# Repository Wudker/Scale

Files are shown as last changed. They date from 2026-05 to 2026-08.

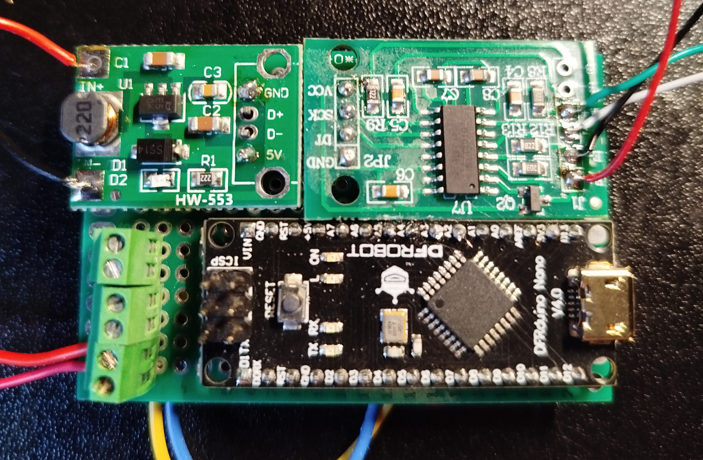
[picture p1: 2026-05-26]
Hardware/Photos/img_01.jpg

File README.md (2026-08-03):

# Load Cell Digital Scale

Load Cell Digital Scale is a compact standalone weighing device built around a strain-gauge load cell, HX711 converter and SSD1306 OLED display. The microcontroller converts the measured signal using an experimentally determined calibration factor and applies exponential filtering to reduce short-term fluctuations. Measurements are displayed in grams or kilograms, while automatic startup tare and a physical button provide zero adjustment. The electronics and weighing platform are integrated into a compact 3D-printed enclosure.

## Technologies

`Arduino` `C/C++` `Load cell` `HX711` `SSD1306 OLED` `Adafruit GFX` `I2C` `Exponential filtering` `3D printing`

## Usage and development status

Place the scale on a stable surface and power it on without any load to allow automatic taring. Use the physical button whenever manual re-taring is required, then place the object on the platform and read its mass from the display. The prototype has been built and tested, but broader validation is still required to evaluate repeatability, drift, nonlinearity and temperature effects. Future improvements may include overload detection and additional measurement compensation.

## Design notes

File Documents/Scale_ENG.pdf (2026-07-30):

# Scale Project

Final Project Documentation

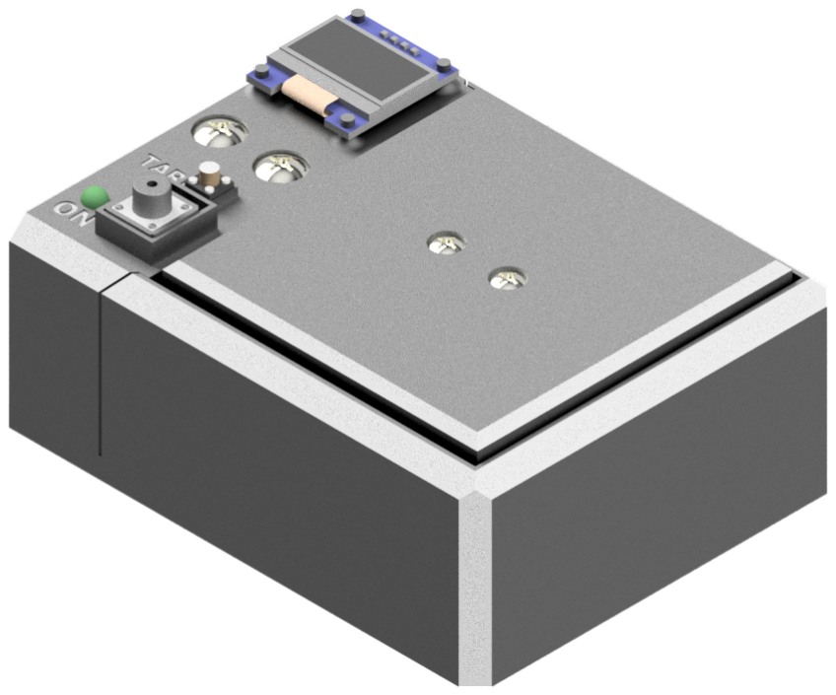
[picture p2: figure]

Author | Bartłomiej Dusza, Eng.
Date | July 20, 2026
Version | 1.0

This document summarizes the project and describes the assumptions, design and operation of the device.

# Contents

1 Introduction | 2
2 Electronics | 3
3 Mechanical Design | 5
4 Software | 7
5 Validation | 12

# 1 Introduction

## 1.1 Objective

The objective of the project was to design and build a simple scale for everyday use.

## 1.2 Operating Principle

The measurement principle is based on the linear relationship between stress and strain in the material from which the load cell is made. According to Hooke’s law, the deformation of the beam is proportional to the applied force. Strain gauges attached to the beam respond to deformation by changing their resistance. Connected in a Wheatstone bridge, they convert this change into a voltage signal.

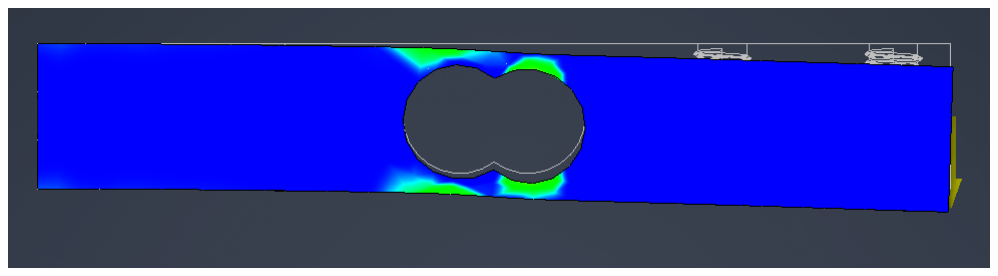
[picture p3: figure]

Figure 1.1: Visualization of load-cell deflection.

Because of the expected loads and material properties, load-cell deflection is very small and reaches only several tens of micrometres. The Wheatstone bridge output therefore requires amplification and conversion before it can be read by the microcontroller.

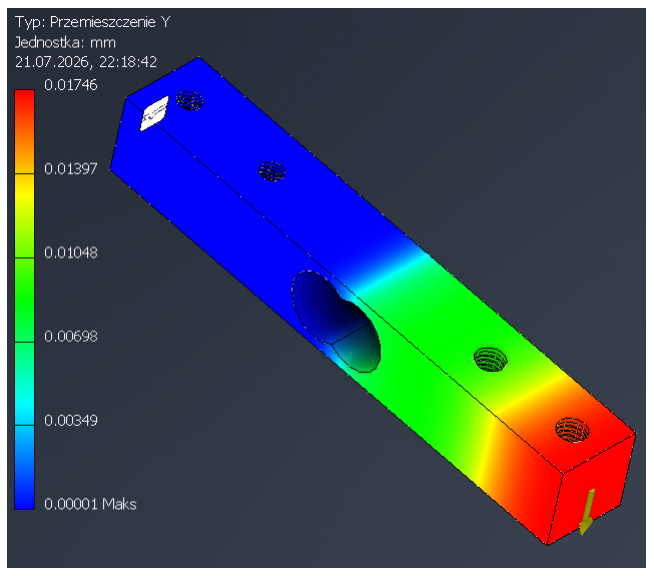
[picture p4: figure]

Figure 1.2: Example load-cell displacement.

# 2 Electronics

## 2.1 Selected Modules

After analyzing the project requirements, ready-made electronic modules were selected.

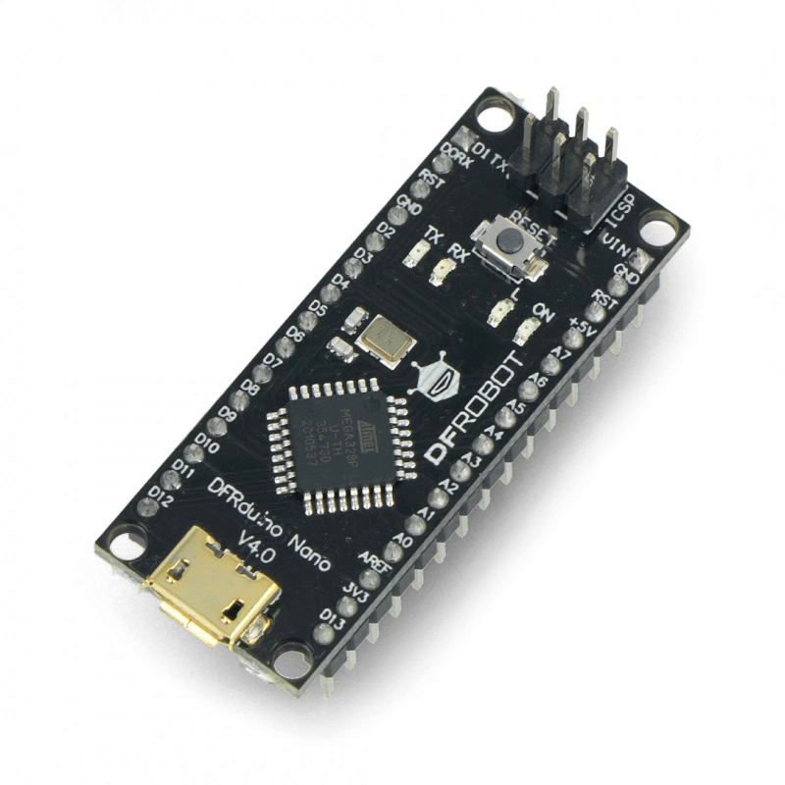
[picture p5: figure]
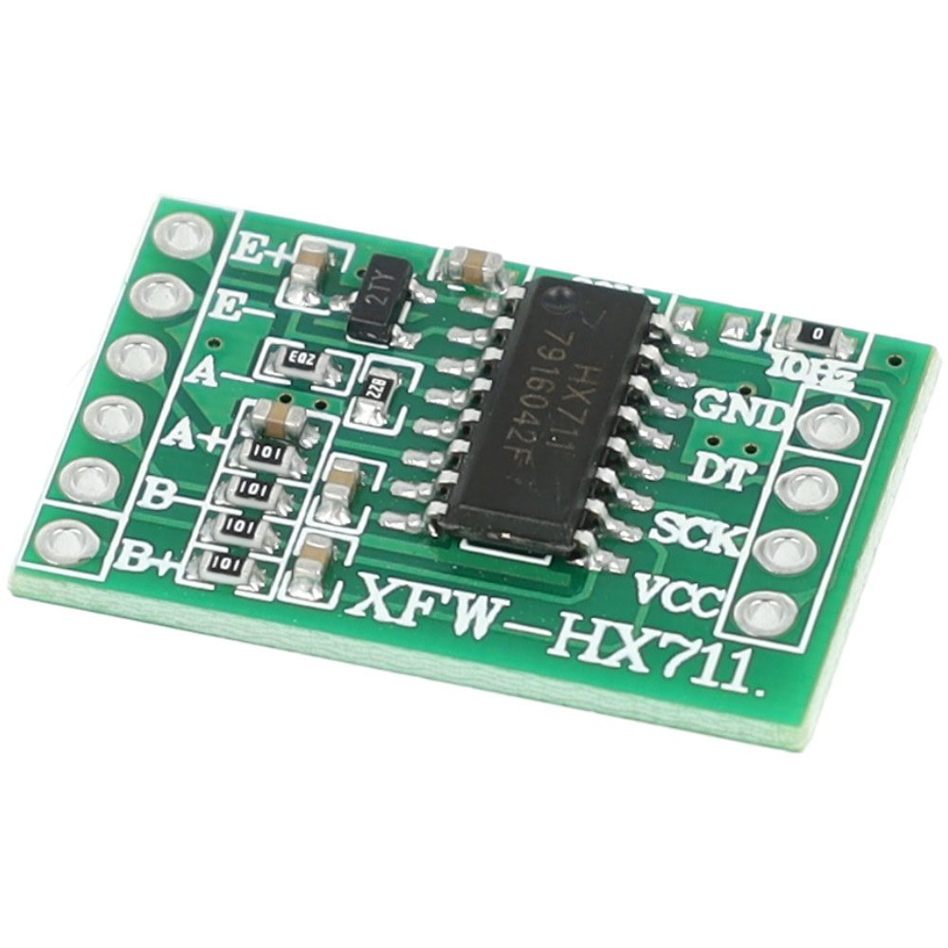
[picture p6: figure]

(a) Microcontroller. | (b) Load-cell amplifier.

The ATtiny85 microcontroller was selected initially. However, because the display had to be supported, it was replaced with the more capable DFRduino Nano development board [1], equipped with an ATmega328 microcontroller. Its availability, sufficient capabilities and favorable purchase price of PLN 20 were the main reasons for this choice.

The HX711 [2], a 24-bit analog-to-digital converter with an integrated programmable gain amplifier, was used to process the Wheatstone bridge signal.

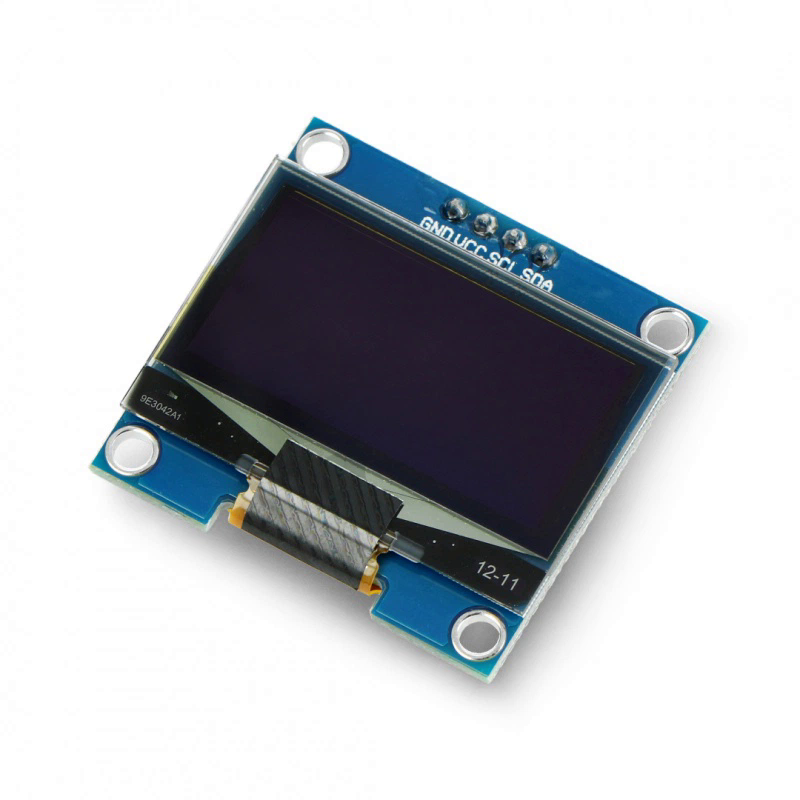
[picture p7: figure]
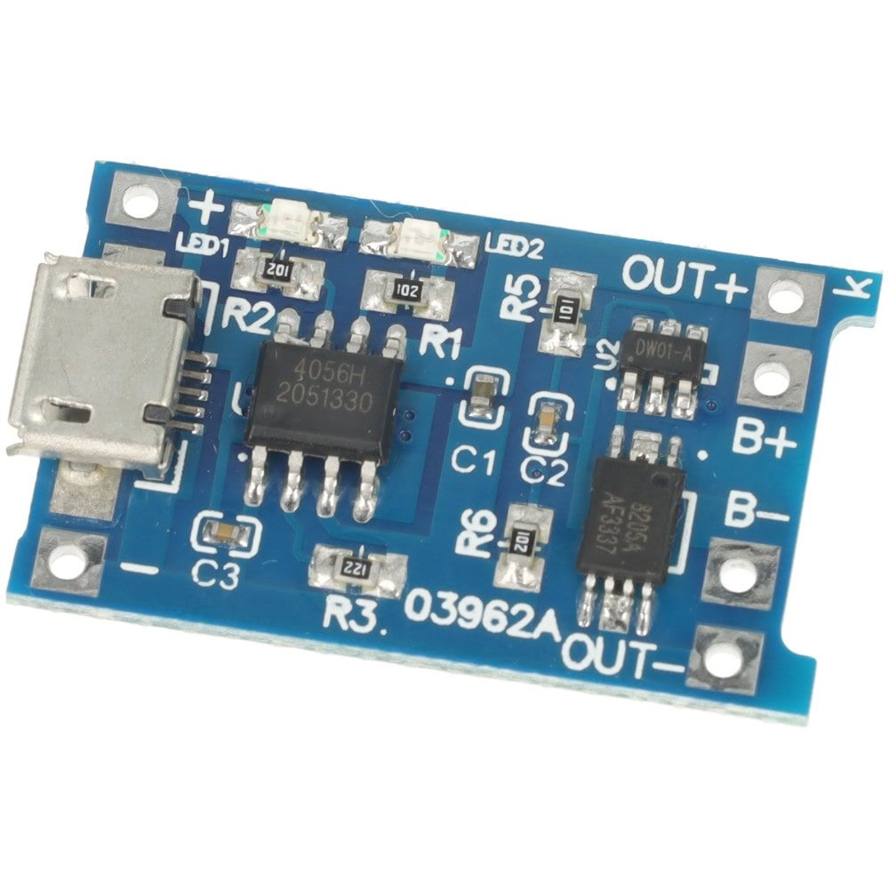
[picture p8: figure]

(a) Cell charging and protection module. | (b) OLED display.

Due to the portable nature of the device, battery power was selected. A module based on the TP4056 [3] is responsible for charging and protecting the cell.

The results are shown on a 0.96-inch OLED display [4], which communicates with the microcontroller through the I2C bus. The modules require a 5 V supply, while the cell voltage is between 3.3 and 4.2 V. A step-up converter was therefore used to provide 5 V [5].

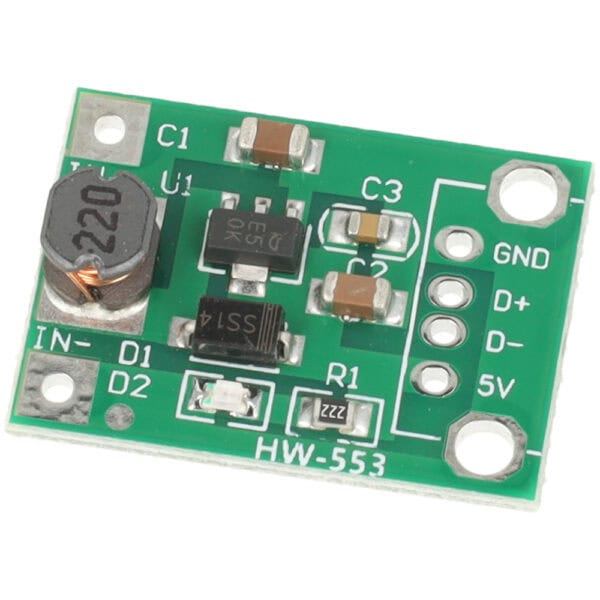
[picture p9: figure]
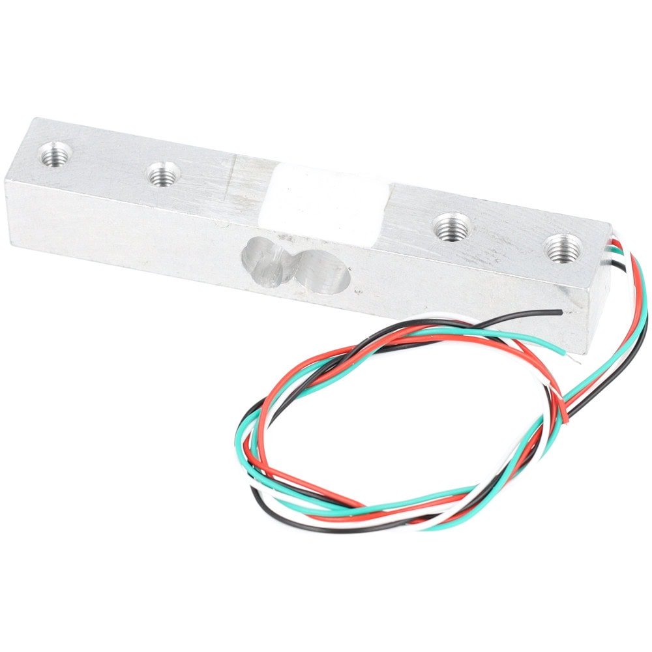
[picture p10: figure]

(a) Load cell. | (b) Step-up converter.

The main measuring component is a load cell [6] with a range of up to 10 kg. Its operating principle is explained in Section 1.2. The range was selected for the expected loads. In a typical kitchen scale, a load cell with a range of 1–2 kg would provide better measurement resolution.

## 2.2 Main Board

The modules were soldered to a prototype board. ARK screw terminals were also installed to simplify wire connections.

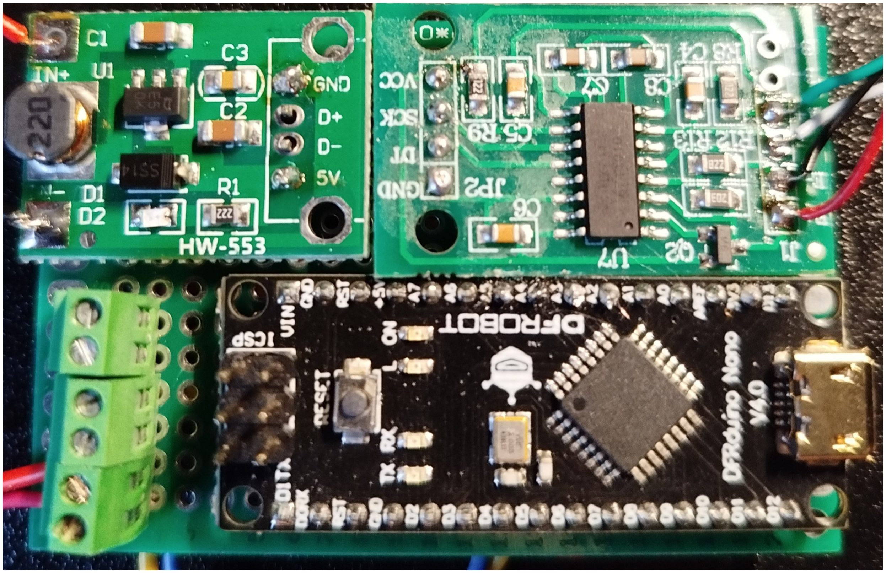
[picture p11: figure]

Figure 2.4: Assembled main board.

# 3 Mechanical Design

The enclosure was designed as a three-part bolted structure consisting of a base, an interface bridge and a weighing platform. It arranges the components compactly and safely while allowing the load cell to operate freely. Later iterations improved the mounting of the threaded inserts and reduced the platform outline to eliminate contact with the base walls. The display and LED were press-fitted into the enclosure after local heating of the plastic.

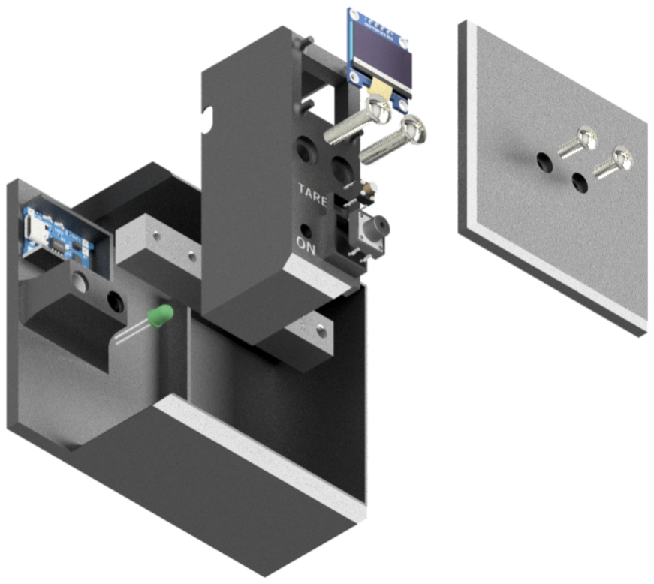
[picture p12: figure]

Figure 3.1: Device assembly.

The base contains the main board, TP4056 module, cell and load cell, which is mounted using two M5 heat-set threaded inserts. A thicker floor and rounded column edges increase the stiffness of the structure.

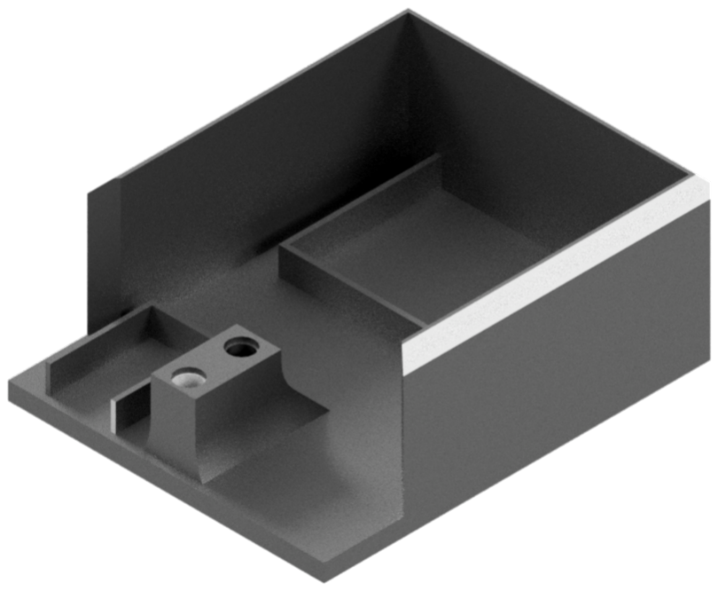
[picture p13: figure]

Figure 3.2: Device base.

The interface bridge contains the display, LED, tare button and power button. It includes holes for M5 screws, four display mounting posts and a cut-out providing access to the USB port of the TP4056 module. Its chamfered walls were matched to the base.

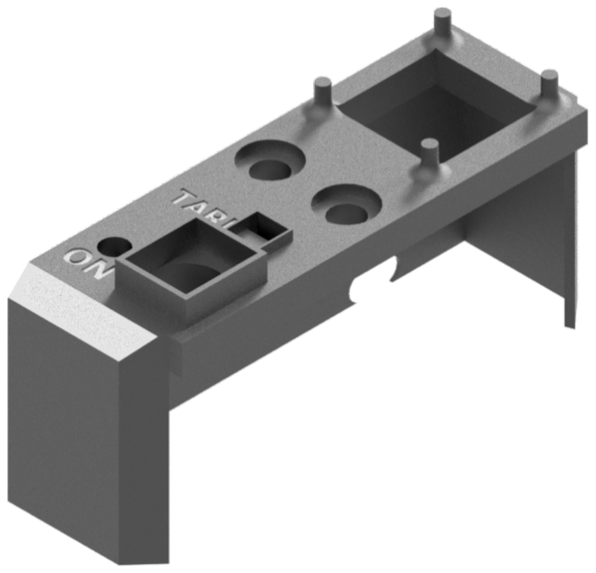
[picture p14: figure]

Figure 3.3: Interface bridge.

The weighing platform has a working area of 73 × 73 mm and chamfered upper corners. It is attached to the load cell with two M4 screws. Its reduced outline prevents contact with the enclosure when the beam deflects.

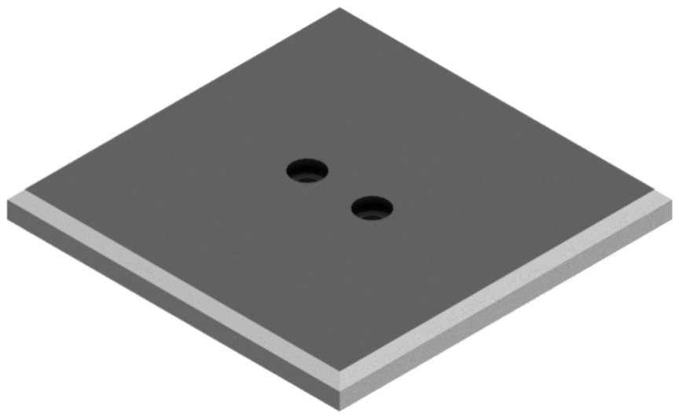
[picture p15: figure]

Figure 3.4: Weighing platform.

# 4 Software

## 4.1 Preliminary Calibration

A calibration factor passed as an argument to the set_scale() function was used to convert the raw HX711 signal into mass. Its initial value was determined using everyday objects and a hammer with a known mass of 590 g. The calibration factor was calculated from:

Scale0 =

Nobc − N0

mref

, | (4.1)

where Nobc is the converter reading after loading the cell, N0 is the unloaded scale reading and mref is the mass of the reference object. For the values obtained experimentally, the factor was:

Scale0 =

181224 − 44012
590
≈ 232.56. | (4.2)

During the first measurements, this value was passed to the scale.set_scale() function. The HX711 library uses it to convert the difference between the current reading and the value determined during taring into a result expressed in grams.

Taring was performed automatically after the device was started and after the button was pressed. The tare() function determined the zero level from 20 samples. At the same time, the value stored by the software filter was reset.

To reduce short-term fluctuations, the getWeightResult() function calculated the average of five converter readings and then applied an exponential filter:

mf (k) = αm(k) + (1 − α)mf (k − 1), | (4.3)

where m(k) is the current measurement result, mf (k) is the filtered result and the α factor was set to 0.8. The result was shown on the OLED display. Values below 1 g were set to zero in software, while results above 1000 g were displayed in kilograms.

The preliminary validation results described in Section 5.1 showed systematic under-reading of the measured mass. Corrected factor values were calculated for each load, and their average was approximately 229.99. The following rounded value was therefore used in the program:

static float scaleFactor = 230.0f;

Reducing the factor from 232.56 to 230.00 increased the calculated result by approximately 1.11%, compensating for the under-reading observed during preliminary validation. This factor was used until a more accurate calibration with a set of test weights was performed.

## 4.2 Final Calibration

The Scale = 230.00 factor was determined by comparison with a commercial kitchen scale. Because its accuracy and calibration status were unknown, this value was treated as the result of preliminary calibration. To determine the sensitivity of the device more accurately, another series of tests was performed using test weights with masses from 10 to 500 g.

Before the measurements, the device was left switched on for approximately 10 minutes to reduce the influence of temperature changes in the load cell and HX711 amplifier. Before each measurement point, the load was removed from the platform and the scale was tared.

For each weight, the difference between the raw converter reading under load and the level determined during taring was calculated:

xi = Nobc,i − N0,i.

A linear conversion model was assumed:

xi ≈ Skmref,i,

where mref,i is the declared mass of the weight and Sk is the final calibration factor to be determined. Its value was calculated by the least-squares method, assuming a straight line passing through the origin:

Sk =

Xn

i=1

mref,ixi
Xn

i=1

m²
ref,i

The measurements gave:

Sk = 232.3866.

This value was rounded to two decimal places and stored in the final version of the program:

static float scaleFactor = 232.39f;

The final calibration result differs from the value of 230.00 determined during preliminary validation. The preliminary factor was based on the readings of a commercial kitchen scale and was affected by zero-level drift. The use of test weights, device warm-up and taring before each point made it possible to determine the sensitivity of the system more accurately.

Increasing the factor from 230.00 to 232.39 proportionally reduces the result returned by the get_units() function. This prevents the over-reading that would occur if the factor of 230.00 were used under stabilized measurement conditions.

### 4.2.1 Linearity Assessment

Before the final calibration, possible nonlinearity of the load-cell characteristic was considered. It could result from beam deformation, the mounting method or the transfer of the load through the platform. For this reason, the use of a quadratic correction was analyzed:
mcorr = K1m + K2m²

The initial measurement series could suggest slight curvature of the characteristic. However, most of this difference disappeared when the scale was tared before each measurement point. This indicates that its main sources were zero-level drift and load-cell creep rather than actual nonlinearity of its sensitivity.

After applying a single linear factor of Sk = 232.39, the maximum absolute error for weights from 10 to 500 g was approximately 0.19 g, while the RMSE was approximately 0.116 g. Fitting a quadratic model reduced the RMSE to approximately 0.071 g, an improvement of only about 0.045 g. This improvement was small compared with the variation observed between measurement series.

In addition, the errors of the linear model changed sign and did not form a clear monotonic trend related to the applied load. Using two factors, K1 and K2, would therefore increase the risk of fitting the function to measurement noise, zero drift and errors in the placement of the weights. For this reason, quadratic correction was not used in the range covered by the calibration weights, i.e. from 10 to 500 g, and the linear model was retained.

This result confirms linearity only within the tested range. It does not prove that the load cell is linear over its entire nominal range of 10 kg.

### 4.2.2 Extended-Range Correction

Certified calibration weights were not available for loads above 500 g. An additional comparison with a commercial kitchen scale was therefore performed. As the mass increased, a systematic under-reading of the constructed scale was observed.

To partially compensate for this difference, a simple continuous piecewise-linear correction was applied:

mcorr =

m, | m ≤ 500 g,

m + c(m − 500), m > 500 g,

where m is the result obtained after applying the factor Sk = 232.39.

The c factor was determined by the least-squares method. The following variable was

defined:
zi = max(mi − 500, 0),

and then:

c =

X

i

zi (mkuch,i − mi)
X

i

z

2
i

≈ 0.003965.

The final function implemented in the program is:

float calibrationCorrection(float grams) {
if (grams <= 500.0f)
return grams;

return grams + 0.003965f * (grams - 500.0f);
}

The advantage of this function is that the result obtained using calibration weights up to 500 g is preserved and no discontinuity occurs at the transition point. This is neither a quadratic correction nor a complete metrological calibration of the extended range. It is only an empirical compensation of the difference observed relative to a kitchen scale whose accuracy and calibration status were unknown.

## 4.3 Filtering and Reading Stabilization

The rate at which new results can be obtained is limited mainly by the sampling rate of the HX711. The delay(1) instruction used in the main program loop is not the main factor determining the measurement time.

In the final version of the program, the get_units(2) function calculates the average of two consecutive samples. This produces a result faster than averaging five samples while still providing basic noise reduction.

An exponential filter is then applied. Its factor is selected according to the change in the reading:
mf (k) = α(k)m(k) + [1 − α(k)] mf (k − 1),

gdzie:

α(k) =

0.85, |m(k) − mf (k − 1)| > 1 g,

0.10, |m(k) − mf (k − 1)| ≤ 1 g.

A high value of α = 0.85 means that 85% of the new result is included in the current iteration. The filter therefore responds quickly when an object is placed on or removed from the platform. Once the reading has stabilized, α = 0.10 is used to provide stronger attenuation of small changes and converter noise.

During taring, the zero level is determined from 25 samples:

scale.tare(25);

filteredWeight = 0;

Resetting the filter variable prevents the previous reading from affecting the next measurement.

The result is displayed with two decimal places. However, the number of displayed digits defines only the presentation format and should not be interpreted as the measurement accuracy of the device.

# 5 Validation

## 5.1 Preliminary Validation

Preliminary validation was performed by comparing the readings of the constructed device with the results of a commercial kitchen scale. Because certified calibration weights were not available at this stage, the kitchen scale was used as the reference device. Therefore, the test did not constitute a complete metrological calibration.

Five objects with masses ranging from approximately 190 g to 1.84 kg were used. Each object was measured alternately using the constructed scale and the reference scale. Three repetitions were performed for each load, and the average readings were then calculated.

Table 5.1: Comparison of average measurement results.

No. | Average measured [g] | Average reference [g] | Difference [g] | Error [%]
1 | 188.23 | 191.00 | 2.77 | 1.45
2 | 1822.67 | 1838.33 | 15.67 | 0.85
3 | 1552.00 | 1566.00 | 14.00 | 0.89
4 | 883.73 | 893.67 | 9.93 | 1.11
5 | 513.60 | 520.00 | 6.40 | 1.23

For all tested objects, the reading of the constructed scale was lower than that of the reference device. The relative error ranged from 0.85% to 1.45%, with an average value of approximately 1.11%. The similar direction of the deviation across the tested range mainly indicates an inaccurate calibration factor rather than a random error.

For each load, a corrected factor can be calculated from:

Scalei = Scale0

mi

mref,i

. | (5.1)

For the initial factor Scale0 = 232.56, the average factor obtained from the five series was:

Scale = 229.99.

For this reason, the following rounded value was used in the program:

static float scaleFactor = 230.0f;

Reducing the factor from 232.56 to 230.00 increased the calculated result by approximately 1.11%, compensating for the systematic under-reading observed relative to the kitchen scale.

This result was treated as a preliminary software correction. Because a certified reference device was not available, the factor had to be determined again using a set of test weights. These tests are described in the final calibration section.

## 5.2 Final Validation Using Calibration Weights

The final measurements were performed at ten points covering nominal masses from 10 to 500 g. The device was left switched on for approximately 10 minutes before the measurements. Before each point, the load was removed, the scale was tared and the weights were then placed in the center of the platform.

Table 5.2 presents the values obtained after applying the final factor Sk = 232.39. The error was defined as:

ei = mk,i − mref,i.

Table 5.2: Assessment of the final calibration-factor fit.

Nominal mass [g] | Value for Sk = 232.39 [g] | Error [g]
10 | 10.02 | 0.02
20 | 19.96 | -0.04
40 | 40.06 | 0.06
60 | 60.09 | 0.09
80 | 79.81 | -0.19
100 | 99.91 | -0.09
150 | 149.87 | -0.13
200 | 199.83 | -0.17
400 | 399.96 | -0.04
500 | 500.17 | 0.17

The mean error, mean absolute error and root mean square error were used for a quantitative assessment of the fit:

e =

1
n

Xn

i=1

ei

,

MAE = 1
n

Xn

i=1

|ei

|,

RMSE =

vuut
1
n

Xn

i=1

e

2
i

For the data in the table:

e = −0.031 g, | MAE = 0.099 g, | RMSE = 0.116 g.

The maximum absolute error was approximately:

|e|max = 0.189 g.

The small mean error indicates that there is no clear systematic over-reading or under-reading after the factor is changed. The changing signs of consecutive errors also do not indicate clear nonlinearity within the tested range.

The presented values were calculated from the same data series that was used to determine the Sk factor. They therefore assess the quality of the fit rather than provide fully independent validation. Independent confirmation of accuracy would require an additional measurement series after storing the factor of 232.39 in the software.

## 5.3 Zero-Drift Assessment

In longer series where taring was performed only before the start of the test, a gradual shift in the reading was observed. This effect could appear similar to nonlinearity or hysteresis, particularly when comparing series performed with increasing and decreasing mass.

After taring before each measurement point, the shift was greatly reduced and the readings again approached the reference values. This indicates that the main sources of the changes were zero-level drift, temperature dependence and load-cell creep.

Taring compensates for the additive component of the error present at the time it is performed, but it does not change the sensitivity of the system or replace a correct calibration factor. It also does not guarantee the removal of changes that occur after the load is applied. The following measurement procedure was therefore adopted:

1. leave the device switched on for approximately 10 minutes,
2. make sure that the platform is unloaded,
3. tare the scale immediately before the measurement,
4. place the object as close to the center of the platform as possible,
5. wait for the reading to stabilize.

## 5.4 Extended-Range Comparison

An additional assessment for masses above 500 g was performed by comparison with a commercial kitchen scale. The results previously obtained using the constructed scale were recalculated using the final factor Sk = 232.39 and the piecewise-linear correction.

Relative to the kitchen-scale readings:

MAE = 1.58 g, RMSE = 1.89 g,

Table 5.3: Extended-range comparison after application of the final correction.

Object | Kitchen scale [g] | Corrected value [g] | Difference [g]
1 | 340 | 340.57 | 0.57
2 | 1290 | 1287.15 | -2.85
3 | 1828 | 1824.96 | -3.04
4 | 1554 | 1551.02 | -2.98
5 | 771 | 770.59 | -0.41
6 | 2425 | 2425.21 | 0.21
7 | 594 | 592.73 | -1.27
8 | 3810 | 3812.03 | 2.03
9 | 3038 | 3039.56 | 1.56
10 | 2129 | 2128.11 | -0.89

while the maximum absolute difference was approximately 3.04 g.

The results indicate that the correction reduced the systematic under-reading observed for larger loads. However, this comparison should be treated only as a verification test. The kitchen scale was not a certified reference device and showed values approximately 1 g higher when the 150, 200 and 400 g weights were measured. In addition, the same results were used both to determine the correction factor and to calculate the presented errors.

Complete validation of the extended range would require certified standards with masses above 500 g and independent measurement series.

## 5.5 Validation Conclusions

Preliminary validation against a commercial kitchen scale led to the selection of the factor Scale = 230.00. This value reduced the initially observed under-reading, but it was only an approximate result because of the accuracy limitations of the reference device.

Final calibration with a set of test weights, after warming up the device and taring before each point, made it possible to determine a more accurate factor:

Sk = 232.39 .

Within the range from 10 to 500 g, the device characteristic can be considered linear with accuracy sufficient for the intended application. A quadratic correction was analyzed, but its effect on the error was small and did not justify increasing the complexity of the model.

For masses above 500 g, an additional piecewise-linear correction was applied. Its effect was assessed by comparison with a kitchen scale, but because no certified standard was available, this result cannot be treated as a complete metrological calibration.

The combination of two-sample averaging, a dynamic exponential filter and taring based on 25 samples provided a compromise between response time and reading stability. Taring before the measurement effectively reduced the observed zero drift, but it did not replace calibration of the device sensitivity.

# Bibliography

[1] Botland. DFRduino Nano V3.1 – kompatybilny z Arduino Nano. Botland. URL: https://botland.com.pl/plytki-zgodne-z-arduino-dfrobot/3035-dfrduinonano - v40 - kompatybilny - z - arduino - nano - 6959420900398 . html (https://botland.com.pl/plytki-zgodne-z-arduino-dfrobot/3035-dfrduino-nano-v40-kompatybilny-z-arduino-nano-6959420900398.html) (visited on 07/19/2026).
[2] Sklep msalamon. Wzmacniacz belki tensometrycznej HX711. Sklep msalamon. URL: https://sklep.msalamon.pl/produkt/wzmacniacz-belki-tensometrycznejhx711/ (https://sklep.msalamon.pl/produkt/wzmacniacz-belki-tensometrycznej-hx711/) (visited on 07/19/2026).
[3] Botland. Ładowarka Li-Ion HW-373 V1.2.1 TP4056 – pojedyncza cela 1S 3,7 V, USB-C, z zabezpieczeniami. Botland. URL: https://botland.com.pl/ladowarkielektryczne / 16979 - ladowarka - li - ion - hw - 373 - v121 - tp4056 - pojedyncza -cela-1s-37v-usb-typ-c-z-zabezpieczeniami-5904422326708.html (https://botland.com.pl/ladowarki-elektryczne/16979-ladowarka-li-ion-hw-373-v121-tp4056-pojedyncza-cela-1s-37v-usb-typ-c-z-zabezpieczeniami-5904422326708.html) (visited on 07/19/2026).
[4] Botland. Wyswietlacz graficzny OLED 1,3 cala, 128x64 px, I2C V2 – niebieskie ´ znaki. Botland. URL: https : / / botland . com . pl / wyswietlacze - oled / 8246 -wyswietlacz- oled- niebieski- graficzny- 13- 128x64px- i2c- v2- niebieskieznaki-5904422311339.html (https://botland.com.pl/wyswietlacze-oled/8246-wyswietlacz-oled-niebieski-graficzny-13-128x64px-i2c-v2-niebieskie-znaki-5904422311339.html) (visited on 07/19/2026).
[5] Sklep msalamon. Mini przetwornica step-up 1–5 V do 5 V 600 mA. Sklep msalamon. URL: https://sklep.msalamon.pl/produkt/mini-przetwornica-step-up-1-5vdo-5v-600-ma/ (https://sklep.msalamon.pl/produkt/mini-przetwornica-step-up-1-5v-do-5v-600-ma/) (visited on 07/22/2026).
[6] Sklep msalamon. Belka tensometryczna do 10 kg / 100 N. Sklep msalamon. URL: https://sklep.msalamon.pl/produkt/belka-tensometryczna-do-10-kg-100-n/ (https://sklep.msalamon.pl/produkt/belka-tensometryczna-do-10-kg-100-n/) (visited on 07/19/2026).

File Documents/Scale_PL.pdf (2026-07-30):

# Projekt Scale

Dokumentacja koncowa projektu ´

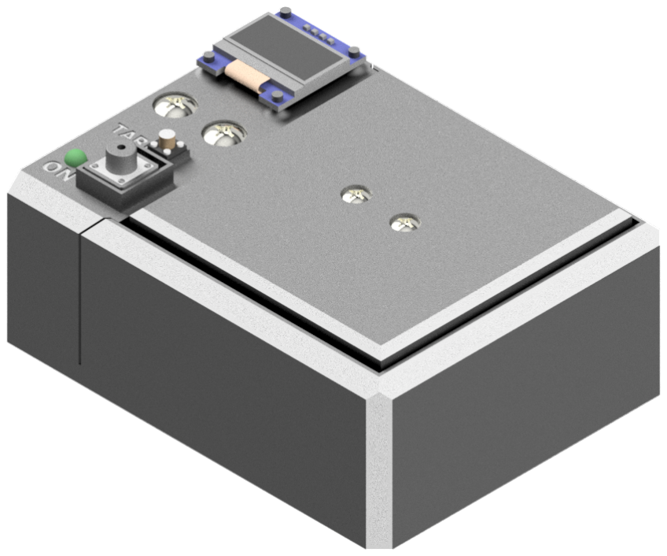
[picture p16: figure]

Autor | inz. Bartłomiej Dusza ˙
Data | 20 lipca 2026
Wersja | 1.0

Niniejszy dokument stanowi podsumowanie realizacji projektu oraz opis załoze˙ n, budowy i ´ działania urz ˛adzenia.

# Spis tresci ´

1 Wst˛ep | 2
2 Elektronika | 3
3 Mechanika | 5
4 Oprogramowanie | 7
4.2 Kalibracja koncowa | ´ | 8
4.2.1 Ocena liniowosci charakterystyki | ´ | 9
5 Walidacja | 12
5.2 Walidacja koncowa z u ´ | zyciem odwa ˙ | zników | ˙ | 13

# 1 Wst˛ep

## 1.1 Cel

Celem projektu było opracowanie i wykonanie prostej wagi do codziennego uzytku. ˙

## 1.2 Zasada działania

Zasada pomiaru wykorzystuje liniow ˛a zalezno ˙ | s´c mi˛edzy napr˛e ´ | zeniem a odkształce- ˙
niem materiału, z którego wykonano belk˛e. Zgodnie z prawem Hooke’a odkształcenie belki jest proporcjonalne do przyłozonej siły. Umieszczone na niej tensometry rezystan- ˙ cyjne reaguj ˛a na odkształcenie zmian ˛a swojej rezystancji. Poł ˛aczone w układ mostka Wheatstone’a umozliwiaj ˛a przekształcenie tej zmiany w sygnał napi˛eciowy. ˙


Rysunek 1.1: Wizualizacja ugi˛ecia belki.

Ze wzgl˛edu na przewidywane obci ˛azenia oraz wła ˙ | sciwo ´ | sci materiału ugi˛ecie belki jest ´
bardzo małe i wynosi zaledwie kilkadziesi ˛at mikrometrów. Sygnał wyjsciowy mostka ´ Wheatstone’a wymaga zatem wzmocnienia i przetworzenia, zanim b˛edzie mógł zostac´ odczytany przez mikrokontroler.


Rysunek 1.2: Przykładowe przemieszczenie belki.

# 2 Elektronika

## 2.1 Wybrane moduły

Po przeanalizowaniu wymagan projektowych zdecydowano si˛e na zastosowanie goto- ´ wych modułów elektronicznych.


(a) Mikrokontroler. | (b) Wzmacniacz belki tensometrycznej.

Pocz ˛atkowo wybrano mikrokontroler ATtiny85, jednak ze wzgl˛edu na koniecznos´c ob- ´ sługi wyswietlacza zast ˛apiono go wydajniejsz ˛a płytk ˛a rozwojow ˛a DFRduino Nano [1], ´
wyposazon ˛a w mikrokontroler ATmega328. Zdecydowały o tym jej dost˛epno ˙ | s´c, wystar- ´
czaj ˛ace mozliwo ˙ | sci oraz korzystna cena, wynosz ˛aca w momencie zakupu 20 zł. ´

Do przetwarzania sygnału z mostka tensometrycznego zastosowano układ HX711 [2], b˛ed ˛acy 24-bitowym przetwornikiem analogowo-cyfrowym ze zintegrowanym, programowalnym wzmacniaczem.

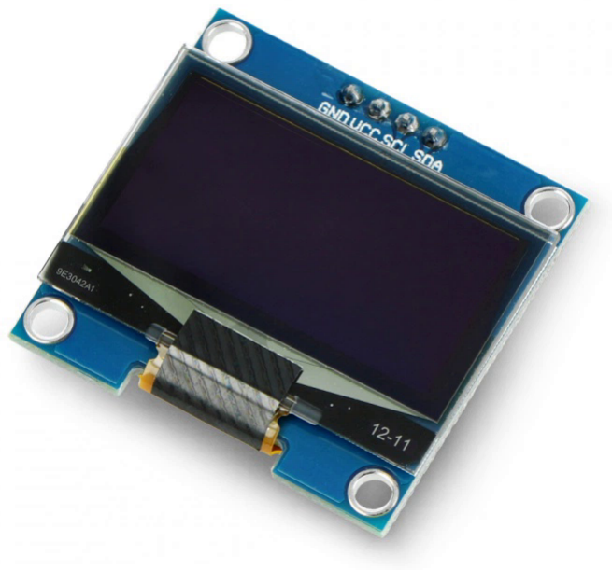
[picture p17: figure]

(a) Moduł ładowania i zabezpieczenia ogniwa. | (b) Wyswietlacz OLED. ´

Ze wzgl˛edu na mobilny charakter urz ˛adzenia zdecydowano si˛e na zasilanie za pomoc ˛a akumulatora. Za ładowanie ogniwa i jego ochron˛e odpowiada moduł z układem TP4056 [3].

Wyniki prezentowane s ˛a na wyswietlaczu OLED o przek ˛atnej 0.96 cala [4], komuni- ´ kuj ˛acym si˛e z mikrokontrolerem za posrednictwem magistrali I2C. Moduły wymagaj ˛a ´ napi˛ecia 5 V, natomiast napi˛ecie ogniwa miesci si˛e w zakresie 3,3–4,2 V. Z tego wzgl˛edu ´ zastosowano przetwornic˛e podwyzszaj ˛ac ˛a napi˛ecie do 5 V [5]. ˙


(a) Belka tensometryczna. | (b) Przetwornica podwyzszaj ˛aca napi˛ecie. ˙

Głównym elementem pomiarowym urz ˛adzenia jest belka tensometryczna [6] o zakresie pomiarowym do 10 kg. Jej zasad˛e działania wyjasniono w podrozdziale 1.2. Zakres ´ dobrano do przewidywanych obci ˛aze˙ n. W przypadku typowej wagi kuchennej zastoso- ´
wanie belki o zakresie 1-2 kg pozwoliłoby uzyskac lepsz ˛a rozdzielczo ´ | s´c pomiaru. ´

## 2.2 Płyta główna

Moduły przylutowano do płytki prototypowej, na której umieszczono równiez zł ˛acza ˙ srubowe ARK, ułatwiaj ˛ace podł ˛aczanie przewodów. ´


Rysunek 2.4: Wykonana płyta główna.

# 3 Mechanika

Obudow˛e zaprojektowano jako trzycz˛esciow ˛a konstrukcj˛e skr˛ecan ˛a, obejmuj ˛ac ˛a pod- ´ staw˛e, mostek i tac˛e. Jej zadaniem jest kompaktowe i bezpieczne rozmieszczenie podzespołów bez ograniczania pracy belki tensometrycznej. W kolejnych iteracjach poprawiono sposób osadzenia wkładek gwintowanych oraz zmniejszono obrys tacy,
eliminuj ˛ac jej kontakt ze scianami podstawy. Wy ´ | swietlacz i diod˛e LED osadzono w ´
obudowie na wcisk, po miejscowym podgrzaniu tworzywa.


Rysunek 3.1: Złozenie urz ˛adzenia. ˙

Podstawa miesci płyt˛e główn ˛a, moduł TP4056, ogniwo oraz belk˛e tensometryczn ˛a ´ mocowan ˛a za pomoc ˛a dwóch wkładek gwintowanych M5. Pogrubione dno i zaokr ˛aglone kraw˛edzie kolumny zwi˛ekszaj ˛a sztywnos´c konstrukcji. ´


Rysunek 3.2: Podstawa urz ˛adzenia.

Mostek skupia elementy interfejsu uzytkownika: wy ˙ | swietlacz, diod˛e LED oraz przyciski ´
tarowania i zasilania. Zawiera otwory pod sruby M5, cztery trzpienie mocuj ˛ace wy ´ | swie- ´
tlacz oraz wyci˛ecie zapewniaj ˛ace dost˛ep do gniazda USB modułu TP4056. Fazowane sciany mostka dopasowano do podstawy. ´


Rysunek 3.3: Mostek urz ˛adzenia.

Taca ma powierzchni˛e robocz ˛a 73 × 73 mm i sfazowane górne naroza. Jest mocowana ˙ do belki dwiema srubami M4, a jej zmniejszony obrys zapobiega kontaktowi z obudow ˛a ´ podczas ugi˛ecia belki.


Rysunek 3.4: Taca urz ˛adzenia.

# 4 Oprogramowanie

## 4.1 Kalibracja wst˛epna

Do przeliczania surowego sygnału z przetwornika HX711 na mas˛e zastosowano współczynnik kalibracyjny przekazywany jako argument funkcji set_scale(). Jego wartos´c´ wyznaczono pocz ˛atkowo za pomoc ˛a przedmiotów codziennego uzytku oraz młotka ˙ o znanej masie wynosz ˛acej 590 g. Współczynnik kalibracyjny obliczono zgodnie z zalezno ˙ sci ˛a: ´

Scale0 =

Nobc − N0

mref

, | (4.1)
gdzie Nobc oznacza odczyt przetwornika po obci ˛azeniu belki, ˙ | N0 jest odczytem nieobci ˛a-
zonej wagi, natomiast ˙ | mref oznacza mas˛e wykorzystanego przedmiotu. Dla otrzymanych
eksperymentalnie wartosci współczynnik wyniósł: ´

Scale0 =

181224 − 44012
590
≈ 232,56. | (4.2)
Podczas pierwszych pomiarów wartos´c ta była przekazywana do funkcji ´ | scale.set_scale().
Biblioteka HX711 wykorzystuje j ˛a do przeliczenia róznicy pomi˛edzy aktualnym odczytem ˙
a wartosci ˛a wyznaczon ˛a podczas tarowania na wynik wyra ´ | zony w gramach. ˙

Tarowanie wykonywane było automatycznie po uruchomieniu urz ˛adzenia oraz po naci-
sni˛eciu przycisku. Funkcja ´ | tare() wyznaczała poziom zerowy na podstawie 20 próbek.
Jednoczesnie zerowana była warto ´ | s´c przechowywana przez filtr programowy. ´

W celu ograniczenia krótkotrwałych zmian wskazania funkcja pobierz_wynik() pobierała sredni ˛a z pi˛eciu odczytów przetwornika, a nast˛epnie stosowała filtr wykładniczy: ´

mf (k) = αm(k) + (1 − α)mf (k − 1), | (4.3)

gdzie m(k) jest aktualnym wynikiem pomiaru, mf (k) wynikiem po filtracji, a współczynnik
α przyjmował wartos´c 0,8. Otrzymany wynik był prezentowany na wy ´ | swietlaczu OLED. ´
Wartosci mniejsze od 1 g były zerowane programowo, natomiast wyniki powy ´ | zej 1000 g ˙
wyswietlano w kilogramach. ´

Na podstawie wyników walidacji wst˛epnej opisanej w punkcie 5.1 stwierdzono systema-
tyczne zanizanie mierzonej masy. Dla poszczególnych obci ˛a ˙ | ze˙ n obliczono skorygowane ´
wartosci współczynnika, których ´ | srednia wyniosła około 229,99. W programie przyj˛eto ´
zatem zaokr ˛aglon ˛a wartos´c:´

static float scaleFactor = 230.0f;

Zmniejszenie współczynnika z 232,56 do 230,00 zwi˛ekszyło wynik zwracany przez funkcj˛e get_units() o około 1,11%, kompensuj ˛ac zanizenie zaobserwowane podczas ˙ walidacji wst˛epnej. Współczynnik ten był wykorzystywany do czasu przeprowadzenia
dokładniejszej kalibracji z uzyciem zestawu odwa ˙ | zników testowych. ˙

## 4.2 Kalibracja koncowa ´

Współczynnik Scale = 230,00 został wyznaczony na podstawie porównania z komercyjn ˛a
wag ˛a kuchenn ˛a. Poniewaz jej dokładno ˙ | s´c i stan wzorcowania nie były znane, warto ´ | s´c t˛e ´
traktowano jako wynik kalibracji wst˛epnej. W celu dokładniejszego okreslenia czuło ´ | sci ´
urz ˛adzenia wykonano kolejn ˛a seri˛e badan z u ´ | zyciem zestawu odwa ˙ | zników testowych o ˙
masach od 10 do 500 g.

Przed rozpocz˛eciem pomiarów urz ˛adzenie pozostawiono wł ˛aczone przez około 10 minut, aby ograniczyc wpływ zmian temperatury belki tensometrycznej i wzmacniacza HX711. ´
Przed kazdym punktem pomiarowym zdejmowano obci ˛a ˙ | zenie z szalki i wykonywano ˙
tarowanie.
Dla kazdego odwa ˙ | znika okre ˙ | slono ró ´ | znic˛e pomi˛edzy surowym odczytem przetwornika ˙
po obci ˛azeniu a poziomem wyznaczonym podczas tarowania: ˙

xi = Nobc,i − N0,i.

Załozono liniowy model przetwarzania: ˙

xi ≈ Skmref,i,

gdzie mref,i oznacza deklarowan ˛a mas˛e odwaznika, natomiast ˙ | Sk jest poszukiwanym
koncowym współczynnikiem kalibracyjnym. Jego warto ´ | s´c wyznaczono metod ˛a najmniej- ´
szych kwadratów, przyjmuj ˛ac prost ˛a przechodz ˛ac ˛a przez pocz ˛atek układu współrz˛ednych:

Sk =

Xn

i=1

mref,ixi
Xn

i=1

m²
ref,i

Dla wykonanych pomiarów otrzymano:

Sk = 232,3866.

Wartos´c t˛e zaokr ˛aglono do dwóch miejsc po przecinku i zapisano w ko ´ | ncowej wersji ´
programu:

static float scaleFactor = 232.39f;

Wynik kalibracji koncowej ró ´ | zni si˛e od warto ˙ | sci 230,00 wyznaczonej podczas walidacji ´
wst˛epnej. Wst˛epny współczynnik opierał si˛e na wskazaniach komercyjnej wagi kuchen-

nej i był obci ˛azony wpływem dryftu poziomu zerowego. Zastosowanie odwa ˙ | zników ˙
testowych, rozgrzanie urz ˛adzenia oraz tarowanie przed kazdym punktem pozwoliły ˙ dokładniej okresli ´ c czuło ´ s´c układu. ´

Zwi˛ekszenie współczynnika z 230,00 do 232,39 powoduje proporcjonalne zmniejszenie wyniku zwracanego przez funkcj˛e get_units(). Zapobiega to zawyzaniu masy, które ˙ wyst˛epowałoby po zastosowaniu współczynnika 230,00 w ustabilizowanych warunkach pomiarowych.

### 4.2.1 Ocena liniowosci charakterystyki ´

Przed przeprowadzeniem koncowej kalibracji rozwa ´ | zano mo ˙ | zliwo ˙ | s´c wyst˛epowania ´
nieliniowosci charakterystyki belki tensometrycznej, wynikaj ˛acej mi˛edzy innymi z jej ´ odkształcenia, sposobu zamocowania oraz przenoszenia obci ˛azenia przez szalk˛e. Z ˙ tego wzgl˛edu analizowano zastosowanie korekcji kwadratowej:

mcorr = K1m + K2m²

Pocz ˛atkowe serie pomiarowe mogły sugerowac niewielkie zakrzywienie charakterystyki. ´
Zaobserwowano jednak, ze po wykonaniu tarowania przed ka ˙ | zdym punktem pomiaro- ˙
wym znaczna cz˛es´c tej ró ´ | znicy zanikała. Oznacza to, ˙ | ze jej głównym ´zródłem był dryft ˙
poziomu zerowego i pełzanie materiału belki, a nie rzeczywista nieliniowos´c jej czuło ´ | sci. ´

Po zastosowaniu jednego współczynnika liniowego Sk = 232,39 maksymalny bł ˛ad
bezwzgl˛edny dla odwazników od 10 do 500 g wyniósł około 0,19 g, natomiast warto ˙ | s´c´
RMSE wyniosła około 0,116 g. Dopasowanie modelu kwadratowego zmniejszało RMSE do około 0,071 g, czyli jedynie o około 0,045 g. Poprawa ta była mała w porównaniu z rozrzutem obserwowanym pomi˛edzy seriami pomiarowymi.

Ponadto bł˛edy modelu liniowego zmieniały znak i nie tworzyły wyra´znego, monotonicz-
nego przebiegu zaleznego od obci ˛a ˙ | zenia. Zastosowanie dwóch współczynników ˙ | K1 i
K2 zwi˛ekszałoby wi˛ec ryzyko dopasowania funkcji do szumu pomiarowego, dryftu zera
i bł˛edów ustawienia odwazników. Z tego wzgl˛edu w zakresie obj˛etym odwa ˙ | znikami ˙
wzorcowymi, tj. od 10 do 500 g, zrezygnowano z korekcji kwadratowej i pozostawiono model liniowy.
Nalezy zaznaczy ˙ | c,´ ze wynik ten potwierdza liniowo ˙ | s´c jedynie w sprawdzonym zakresie. ´
Nie stanowi on dowodu liniowosci belki w całym zakresie znamionowym wynosz ˛acym ´ 10 kg.

### 4.2.2 Korekcja rozszerzonego zakresu

Dla obci ˛aze˙ n wi˛ekszych ni ´ | z 500 g nie dysponowano certyfikowanymi odwa ˙ | znikami. ˙
Przeprowadzono zatem pomocnicze porównanie z komercyjn ˛a wag ˛a kuchenn ˛a. Wraz ze wzrostem masy zaobserwowano systematyczne zanizanie wskazania wykonanej ˙ wagi.
W celu cz˛esciowego skompensowania tej ró ´ | znicy zastosowano prost ˛a, ci ˛agł ˛a korekcj˛e ˙

odcinkowo-liniow ˛a:

mcorr =

m, | m ≤ 500 g,

m + c(m − 500), m > 500 g,

gdzie m oznacza wynik uzyskany po zastosowaniu współczynnika Sk = 232,39.

Współczynnik c wyznaczono metod ˛a najmniejszych kwadratów. Przyj˛eto:

zi = max(mi − 500, 0),

a nast˛epnie:

c =

X

i

zi (mkuch,i − mi)
X

i

z

2
i
| ≈ 0,003965.
Koncowa funkcja zaimplementowana w programie ma posta ´ | c:´

float calibrationCorrection(float grams)
{
if (grams <= 500.0f)
return grams;

return grams + 0.003965f * (grams - 500.0f);
}

Zalet ˛a takiej funkcji jest zachowanie wyniku uzyskanego za pomoc ˛a odwazników wzor- ˙ cowych do 500 g oraz brak skoku wskazania w punkcie przejscia. Nie jest to korekcja ´ kwadratowa ani pełna kalibracja metrologiczna rozszerzonego zakresu. Jest to jedynie empiryczna kompensacja róznicy zaobserwowanej wzgl˛edem wagi kuchennej, której ˙ dokładnos´c i stan wzorcowania nie były znane. ´

## 4.3 Filtracja i stabilizacja wskazania

Cz˛estotliwos´c uzyskiwania kolejnych wyników jest ograniczona przede wszystkim przez ´
cz˛estotliwos´c próbkowania układu HX711. Opó´znienie ´ | | delay(1) zastosowane w głównej
p˛etli programu nie jest głównym czynnikiem wyznaczaj ˛acym czas pomiaru.
W koncowej wersji programu funkcja ´ | get_units(2) oblicza sredni ˛a z dwóch kolejnych ´
próbek. Pozwala to szybciej uzyskac wynik ni ´ | z w przypadku u ˙ | sredniania pi˛eciu próbek, ´
przy jednoczesnym zachowaniu podstawowego tłumienia szumu.

Nast˛epnie wykorzystywany jest filtr wykładniczy ze współczynnikiem dobieranym zalez-˙ nie od zmiany wskazania:

mf (k) = α(k)m(k) + [1 − α(k)] mf (k − 1),

gdzie:

α(k) =

0,85, |m(k) − mf (k − 1)| > 1 g,

0,10, |m(k) − mf (k − 1)| ≤ 1 g.

Duza warto ˙ | s´c´ α = 0,85 powoduje, ze 85% nowego wyniku jest uwzgl˛edniane ju ˙ | z w˙
biez ˛acej iteracji. Filtr szybko reaguje wi˛ec na poło ˙ | zenie lub zdj˛ecie przedmiotu z szalki. ˙
Po ustabilizowaniu wskazania stosowana jest wartos´c´ α = 0,10, która silniej tłumi niewielkie zmiany i szum przetwornika.

Podczas tarowania poziom zerowy wyznaczany jest na podstawie 25 próbek:

scale.tare(25);
filteredWeight = 0;

Wyzerowanie zmiennej filtra zapobiega przenoszeniu poprzedniego wskazania do kolejnego pomiaru.

Wynik jest prezentowany na wyswietlaczu z dwoma miejscami po przecinku. Liczba ´
wyswietlanych cyfr okre ´ | sla jednak wył ˛acznie sposób prezentacji wyniku i nie powinna ´
byc uto ´ | zsamiana z dokładno ˙ | sci ˛a pomiarow ˛a urz ˛adzenia. ´

# 5 Walidacja

## 5.1 Walidacja wst˛epna

Wst˛epn ˛a walidacj˛e przeprowadzono przez porównanie wskazan wykonanego urz ˛a- ´ dzenia z wynikami komercyjnej wagi kuchennej. Ze wzgl˛edu na brak certyfikowanych odwazników waga kuchenna pełniła funkcj˛e urz ˛adzenia odniesienia, a przeprowadzone ˙ badanie nie stanowi pełnej kalibracji metrologicznej.

Do pomiarów wykorzystano pi˛ec przedmiotów o masach obejmuj ˛acych zakres od około ´ 190 g do 1,84 kg. Kazdy przedmiot mierzono naprzemiennie na wykonanej wadze oraz ˙
na wadze odniesienia. Dla kazdego obci ˛a ˙ | zenia przeprowadzono trzy powtórzenia, a ˙
nast˛epnie obliczono srednie warto ´ | sci wskaza ´ | n.´

Tabela 5.1: Porównanie srednich wyników pomiarów. ´

Nr | Sr. otrzymana [g] ´ | Sr. odniesienia [g] ´ | Róznica [g] ˙ | Bł ˛ad [%]
1 | 188,23 | 191,00 | 2,77 | 1,45
2 | 1822,67 | 1838,33 | 15,67 | 0,85
3 | 1552,00 | 1566,00 | 14,00 | 0,89
4 | 883,73 | 893,67 | 9,93 | 1,11
5 | 513,60 | 520,00 | 6,40 | 1,23

Dla wszystkich badanych przedmiotów wskazanie wykonanej wagi było mniejsze od wskazania urz ˛adzenia odniesienia. Bł ˛ad wzgl˛edny miescił si˛e w zakresie od 0,85% ´
do 1,45%, natomiast jego srednia warto ´ | s´c wyniosła około 1,11%. Podobny kierunek ´
odchylenia w całym badanym zakresie wskazuje przede wszystkim na niedokładne dobranie współczynnika kalibracyjnego, a nie na przypadkowy charakter bł˛edu.
Dla poszczególnych obci ˛aze˙ n skorygowany współczynnik mo ´ | zna wyznaczy ˙ | c z zale ´ | zno- ˙
sci: ´

Scalei = Scale0

mi

mref,i

. | (5.1)
Dla współczynnika pocz ˛atkowego Scale0 = 232,56 srednia warto ´ | s´c współczynnika ´
otrzymana dla pi˛eciu serii wyniosła:

Scale = 229,99.

Z tego wzgl˛edu w programie przyj˛eto zaokr ˛aglon ˛a wartos´c:´

static float scaleFactor = 230.0f;

Zmniejszenie współczynnika z 232,56 do 230,00 zwi˛ekszało obliczany wynik o około

1,11%, kompensuj ˛ac systematyczne zanizenie wskaza ˙ | n zaobserwowane wzgl˛edem ´
wagi kuchennej.

Wynik ten potraktowano jako wst˛epn ˛a korekcj˛e oprogramowania. Ze wzgl˛edu na brak certyfikowanego urz ˛adzenia odniesienia konieczne było ponowne wyznaczenie współ-
czynnika z uzyciem zestawu odwa ˙ | zników testowych. Badania te opisano w punkcie ˙
dotycz ˛acym kalibracji koncowej. ´

## 5.2 Walidacja koncowa z u˙zyciem odwa˙zników ´

Koncowe pomiary wykonano dla dziesi˛eciu punktów pomiarowych obejmuj ˛acych dekla- ´ rowane masy odwazników od 10 do 500 g. Urz ˛adzenie przed pomiarami pozostawiono ˙
wł ˛aczone przez około 10 minut. Przed kazdym punktem zdejmowano obci ˛a ˙ | zenie, wyko- ˙
nywano tarowanie, a nast˛epnie umieszczano odwazniki w ˙ | srodkowej cz˛e ´ | sci szalki. ´
W tabeli 5.2 przedstawiono wartosci otrzymane po zastosowaniu ko ´ | ncowego współ- ´
czynnika Sk = 232,39. Bł ˛ad zdefiniowano jako:

ei = mk,i − mref,i.

Tabela 5.2: Ocena dopasowania koncowego współczynnika kalibracyjnego. ´

Masa odwa˙znika [g] | Wartos´c dla ´ Sk = 232,39 [g] | Bł ˛ad [g]
10 | 10,02 | 0,02
20 | 19,96 | -0,04
40 | 40,06 | 0,06
60 | 60,09 | 0,09
80 | 79,81 | -0,19
100 | 99,91 | -0,09
150 | 149,87 | -0,13
200 | 199,83 | -0,17
400 | 399,96 | -0,04
500 | 500,17 | 0,17
Do ilosciowej oceny dopasowania wykorzystano bł ˛ad ´ | sredni, ´ | sredni bł ˛ad bezwzgl˛edny ´
oraz pierwiastek bł˛edu sredniokwadratowego: ´

e =

1
n

Xn

i=1

ei

,

MAE = 1
n

Xn

i=1

|ei

|,

RMSE =

vuut
1
n

Xn

i=1

e

2
i

Dla danych z tabeli otrzymano:

e = −0,031 g, | MAE = 0,099 g, | RMSE = 0,116 g.

Najwi˛ekszy bł ˛ad bezwzgl˛edny wyniósł około:

|e|max = 0,189 g.

Niewielka wartos´c bł˛edu ´ | sredniego wskazuje, ´ | ze po zmianie współczynnika nie wyst˛e- ˙
puje wyra´zne systematyczne zawyzanie ani zani ˙ | zanie wyniku. Zmiana znaków kolejnych ˙
bł˛edów równiez nie wskazuje na jednoznaczn ˛a nieliniowo ˙ | s´c charakterystyki w badanym ´
zakresie.

Przedstawione wartosci zostały obliczone na podstawie tej samej serii danych, któr ˛a ´ wykorzystano do wyznaczenia współczynnika Sk. Stanowi ˛a wi˛ec ocen˛e jakosci dopaso- ´
wania, a nie całkowicie niezalezn ˛a walidacj˛e. Niezale ˙ | zne potwierdzenie dokładno ˙ | sci wy- ´
magałoby wykonania dodatkowej serii pomiarowej po zapisaniu współczynnika 232,39 w oprogramowaniu.

## 5.3 Ocena dryftu poziomu zerowego

W dłuzszych seriach, w których tarowanie wykonywano wył ˛acznie przed rozpocz˛eciem ˙ badania, obserwowano stopniowe przesuni˛ecie wskazania. Efekt ten mógł pozornie
przypominac nieliniowo ´ | s´c lub histerez˛e, szczególnie podczas porównywania serii wyko- ´
nywanych ze wzrastaj ˛ac ˛a i malej ˛ac ˛a mas ˛a.

Po zastosowaniu tarowania przed kazdym punktem pomiarowym przesuni˛ecie zostało ˙
w znacznym stopniu ograniczone, a wskazania ponownie zblizyły si˛e do warto ˙ | sci ´
wzorcowych. Wskazuje to, ze głównym ´zródłem zmian był dryft poziomu zerowego, ˙ zalezno ˙ s´c temperaturowa oraz pełzanie belki tensometrycznej. ´

Tarowanie kompensuje składow ˛a addytywn ˛a bł˛edu wyst˛epuj ˛ac ˛a w chwili jego wykonania, ale nie zmienia czułosci układu i nie zast˛epuje poprawnego współczynnika kalibracyj- ´
nego. Nie gwarantuje równiez usuni˛ecia zmian pojawiaj ˛acych si˛e ju ˙ | z po obci ˛a ˙ | zeniu ˙
belki. Z tego wzgl˛edu przyj˛eto nast˛epuj ˛ac ˛a procedur˛e pomiarow ˛a:
1. pozostawienie urz ˛adzenia wł ˛aczonego przez około 10 minut,
2. sprawdzenie, czy szalka jest nieobci ˛azona, ˙
3. wykonanie tarowania bezposrednio przed pomiarem, ´
4. umieszczenie przedmiotu mozliwie centralnie na szalce, ˙
5. odczekanie do ustabilizowania wskazania.

## 5.4 Porównanie w rozszerzonym zakresie

Pomocnicz ˛a ocen˛e działania dla mas wi˛ekszych niz 500 g wykonano przez porównanie ˙ z komercyjn ˛a wag ˛a kuchenn ˛a. Wyniki uzyskane wczesniej przez wykonan ˛a wag˛e ´
przeliczono zgodnie z koncowym współczynnikiem ´ | Sk = 232,39 oraz korekcj ˛a odcinkowo-
liniow ˛a.

Tabela 5.3: Porównanie w rozszerzonym zakresie po zastosowaniu koncowej korekcji. ´

Przedmiot | Waga kuchenna [g] | Wartos´c po korekcji [g] ´ | Ró˙znica [g]
1 | 340 | 340,57 | 0,57
2 | 1290 | 1287,15 | -2,85
3 | 1828 | 1824,96 | -3,04
4 | 1554 | 1551,02 | -2,98
5 | 771 | 770,59 | -0,41
6 | 2425 | 2425,21 | 0,21
7 | 594 | 592,73 | -1,27
8 | 3810 | 3812,03 | 2,03
9 | 3038 | 3039,56 | 1,56
10 | 2129 | 2128,11 | -0,89

Wzgl˛edem wskazan wagi kuchennej otrzymano: ´

MAE = 1,58 g, RMSE = 1,89 g,

natomiast najwi˛eksza róznica bezwzgl˛edna wyniosła około 3,04 g. ˙

Wyniki wskazuj ˛a, ze zastosowana korekcja ograniczyła systematyczne zani ˙ | zanie od- ˙
czytu obserwowane dla wi˛ekszych obci ˛aze˙ n. Porównanie to nale ´ | zy jednak traktowa ˙ | c´
wył ˛acznie jako badanie kontrolne. Waga kuchenna nie była certyfikowanym urz ˛adzeniem odniesienia, a podczas pomiarów odwazników 150, 200 i 400 g wskazywała ˙ wartosci wi˛eksze o około 1 g. Dodatkowo te same wyniki wykorzystano do wyznaczenia ´ współczynnika korekcji i do obliczenia przedstawionych bł˛edów.

Pełna walidacja rozszerzonego zakresu wymagałaby zastosowania certyfikowanych
wzorców o masach wi˛ekszych niz 500 g oraz wykonania niezale ˙ | znych serii pomiaro- ˙
wych.

## 5.5 Wnioski z walidacji

Walidacja wst˛epna wykonana wzgl˛edem komercyjnej wagi kuchennej doprowadziła do przyj˛ecia współczynnika Scale = 230,00. Wartos´c ta ograniczyła obserwowane pocz ˛at- ´
kowo zanizenie wskaza ˙ | n, lecz ze wzgl˛edu na niedokładno ´ | s´c urz ˛adzenia odniesienia ´
miała charakter orientacyjny.
Koncowa kalibracja z u ´ | zyciem zestawu odwa ˙ | zników testowych, po rozgrzaniu urz ˛adze- ˙
nia i wykonaniu tarowania przed kazdym punktem, pozwoliła wyznaczy ˙ | c dokładniejszy ´
współczynnik:

Sk = 232,39 | .
W zakresie od 10 do 500 g charakterystyk˛e urz ˛adzenia mozna uzna ˙ | c za liniow ˛a z ´
dokładnosci ˛a wystarczaj ˛ac ˛a dla zało ´ | zonego zastosowania. Korekcja kwadratowa była ˙
analizowana, lecz jej wpływ na bł ˛ad był niewielki i nie uzasadniał zwi˛ekszania złozono ˙ | sci ´
modelu.

Dla mas powyzej 500 g zastosowano pomocnicz ˛a korekcj˛e odcinkowo-liniow ˛a. Jej wpływ ˙ oceniono przez porównanie z wag ˛a kuchenn ˛a, lecz ze wzgl˛edu na brak certyfikowanego wzorca wynik ten nie moze by ˙ c traktowany jako pełna kalibracja metrologiczna. ´

Poł ˛aczenie usredniania dwóch próbek, dynamicznego filtra wykładniczego oraz taro- ´ wania na podstawie 25 próbek zapewniło kompromis pomi˛edzy czasem odpowiedzi a stabilnosci ˛a wskazania. Tarowanie przed pomiarem skutecznie ograniczało obserwo- ´ wany dryft zera, ale nie zast˛epowało kalibracji czułosci urz ˛adzenia. ´

# Bibliografia

[1] Botland. DFRduino Nano V3.1 – kompatybilny z Arduino Nano. Botland. URL: https://botland.com.pl/plytki-zgodne-z-arduino-dfrobot/3035-dfrduinonano - v40 - kompatybilny - z - arduino - nano - 6959420900398 . html (https://botland.com.pl/plytki-zgodne-z-arduino-dfrobot/3035-dfrduino-nano-v40-kompatybilny-z-arduino-nano-6959420900398.html) (term. wiz.
19. 07. 2026).
[2] Sklep msalamon. Wzmacniacz belki tensometrycznej HX711. Sklep msalamon. URL: https://sklep.msalamon.pl/produkt/wzmacniacz-belki-tensometrycznejhx711/ (https://sklep.msalamon.pl/produkt/wzmacniacz-belki-tensometrycznej-hx711/) (term. wiz. 19. 07. 2026).
[3] Botland. Ładowarka Li-Ion HW-373 V1.2.1 TP4056 – pojedyncza cela 1S 3,7 V, USB-C, z zabezpieczeniami. Botland. URL: https://botland.com.pl/ladowarkielektryczne / 16979 - ladowarka - li - ion - hw - 373 - v121 - tp4056 - pojedyncza -cela-1s-37v-usb-typ-c-z-zabezpieczeniami-5904422326708.html (https://botland.com.pl/ladowarki-elektryczne/16979-ladowarka-li-ion-hw-373-v121-tp4056-pojedyncza-cela-1s-37v-usb-typ-c-z-zabezpieczeniami-5904422326708.html) (term. wiz.
19. 07. 2026).
[4] Botland. Wyswietlacz graficzny OLED 1,3 cala, 128x64 px, I2C V2 – niebieskie ´ znaki. Botland. URL: https : / / botland . com . pl / wyswietlacze - oled / 8246 -wyswietlacz- oled- niebieski- graficzny- 13- 128x64px- i2c- v2- niebieskieznaki-5904422311339.html (https://botland.com.pl/wyswietlacze-oled/8246-wyswietlacz-oled-niebieski-graficzny-13-128x64px-i2c-v2-niebieskie-znaki-5904422311339.html) (term. wiz. 19. 07. 2026).
[5] Sklep msalamon. Mini przetwornica step-up 1–5 V do 5 V 600 mA. Sklep msalamon. URL: https://sklep.msalamon.pl/produkt/mini-przetwornica-step-up-1-5vdo-5v-600-ma/ (https://sklep.msalamon.pl/produkt/mini-przetwornica-step-up-1-5v-do-5v-600-ma/) (term. wiz. 22. 07. 2026).
[6] Sklep msalamon. Belka tensometryczna do 10 kg / 100 N. Sklep msalamon. URL: https://sklep.msalamon.pl/produkt/belka-tensometryczna-do-10-kg-100-n/ (https://sklep.msalamon.pl/produkt/belka-tensometryczna-do-10-kg-100-n/) (term. wiz. 19. 07. 2026).

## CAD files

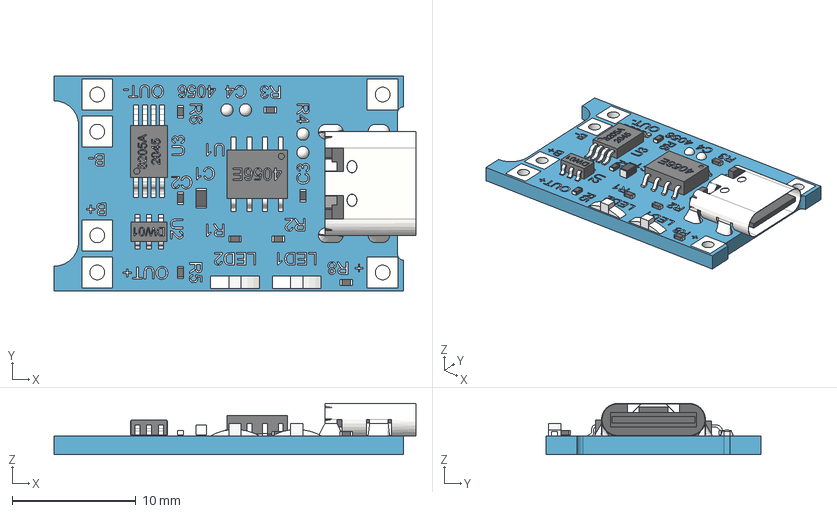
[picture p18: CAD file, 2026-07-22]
Hardware/Model/Parts/TP4056_Charging_Module_Type_C.step
29.3 x 17.4 x 4.14 mm
board
USB_Type_C_Connector
8205A_2045
DW01-P
small1005_smd_resistor x 2
small1005_smd_resistor (1)
small1005_smd_capacitor
smd_capacitor
SOP-8_4056E
solder_dot_round
solder_dot_round (1)
solder_dot_round (2)
solder_dot_round (3)
small1005_smd_capacitor (1)
LED2
LED2 (1)
small1005_smd_resistor (2)
small1005_smd_resistor (4) x 2
soldering

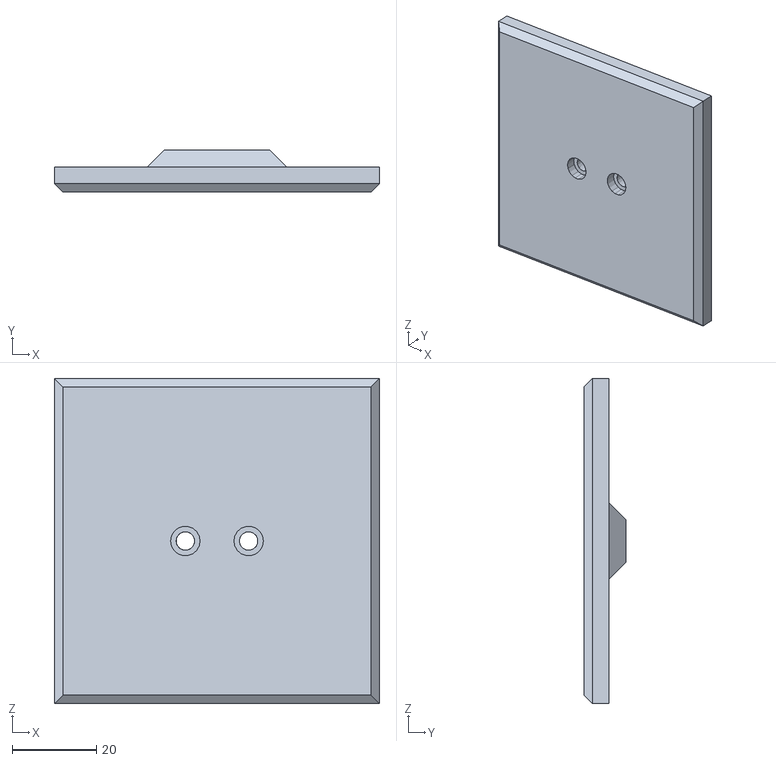
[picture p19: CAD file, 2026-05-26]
Hardware/Model/STL/taca.stl
77.0 x 10.0 x 77.0

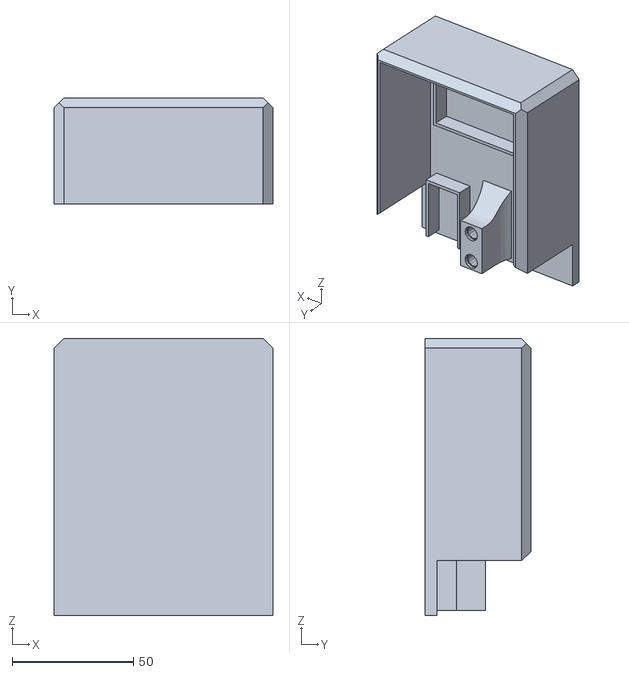
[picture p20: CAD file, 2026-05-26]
Hardware/Model/STL/bridz.stl
90.0 x 43.7 x 114.0

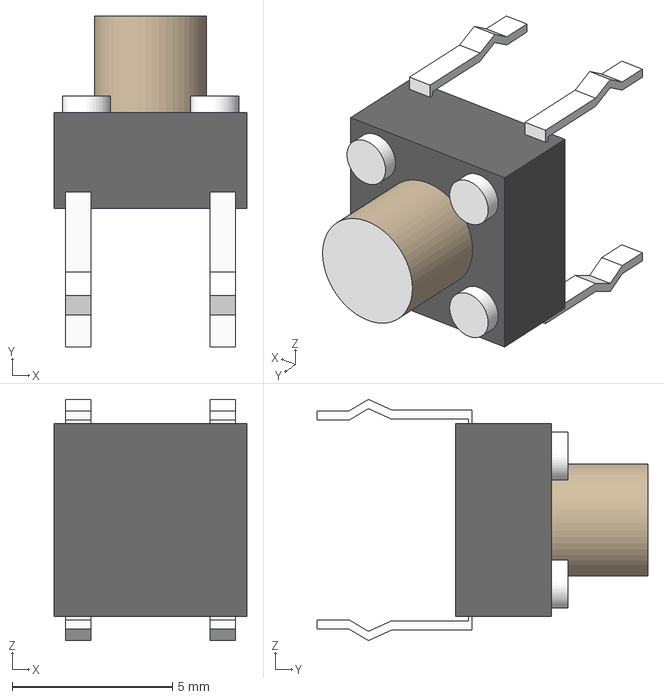
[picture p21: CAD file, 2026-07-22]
Hardware/Model/Parts/mypushbutton.stp
6.00 x 10.3 x 7.52 mm

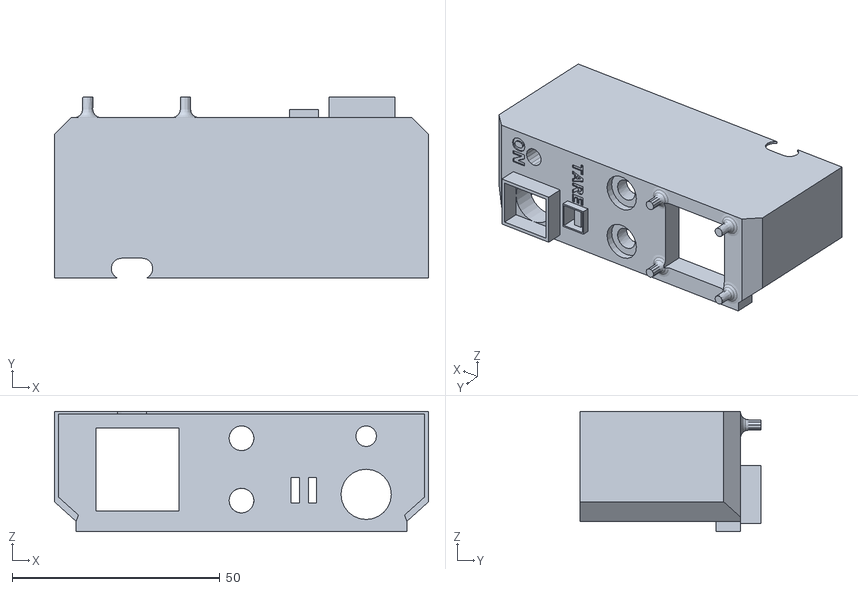
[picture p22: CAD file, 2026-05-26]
Hardware/Model/STL/klappa.stl
90.0 x 43.6 x 29.0

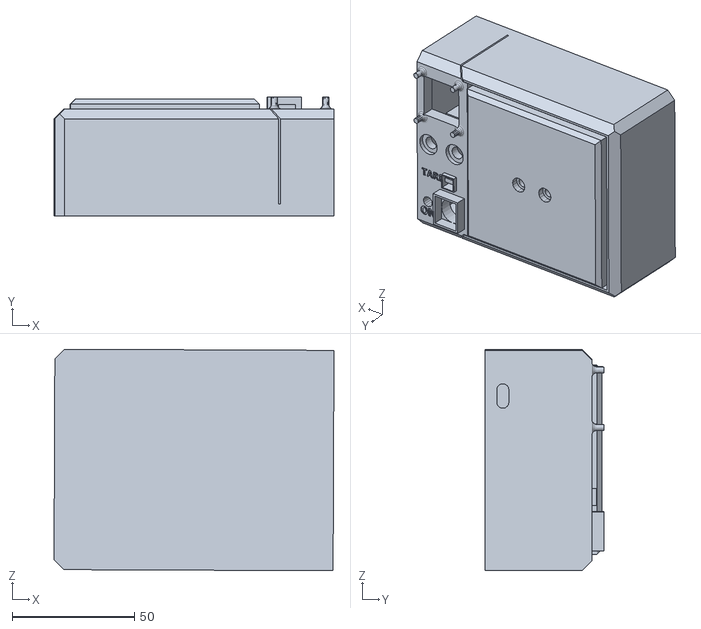
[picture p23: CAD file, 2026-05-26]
Hardware/Model/STL/Zespół1.stl
114.4 x 48.6 x 90.4

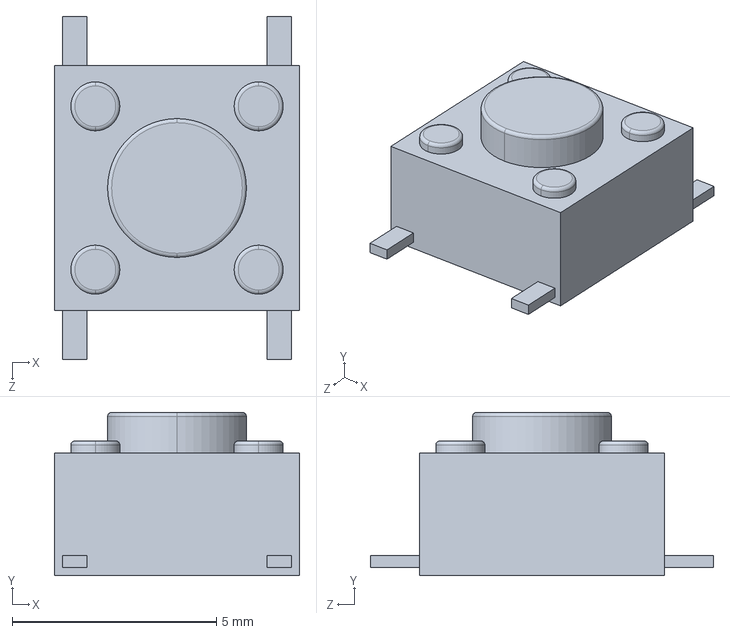
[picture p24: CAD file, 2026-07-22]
Hardware/Model/Parts/Micro_Button_6x6.STEP
6.00 x 4.00 x 8.40 mm

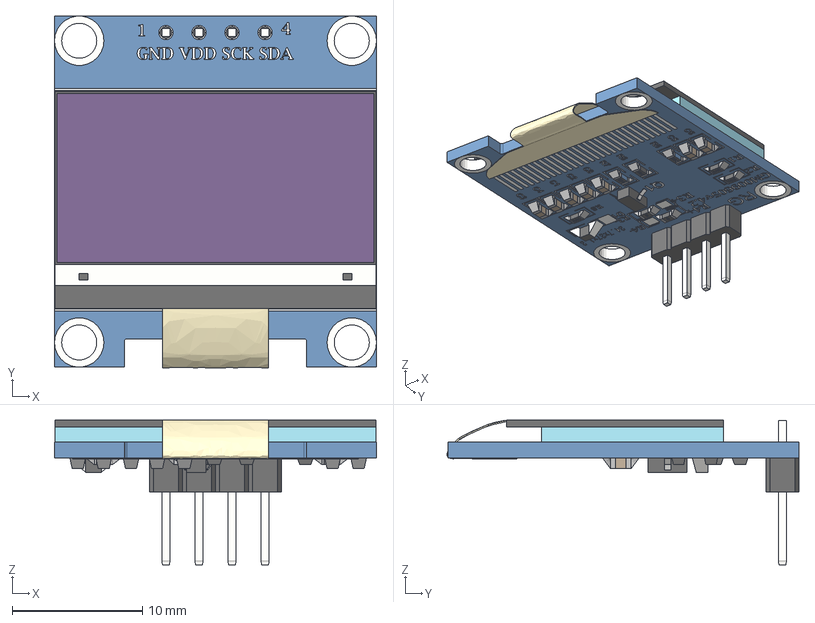
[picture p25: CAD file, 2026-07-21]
Hardware/Model/Parts/0.96'' OLED Display.step
24.8 x 27.1 x 11.1 mm

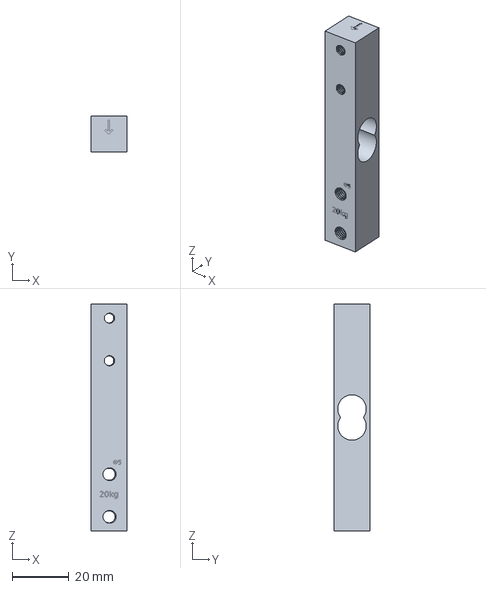
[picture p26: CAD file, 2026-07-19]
Hardware/Model/Parts/LoadCell-20kg-80mm.step
12.7 x 12.7 x 80.0 mm

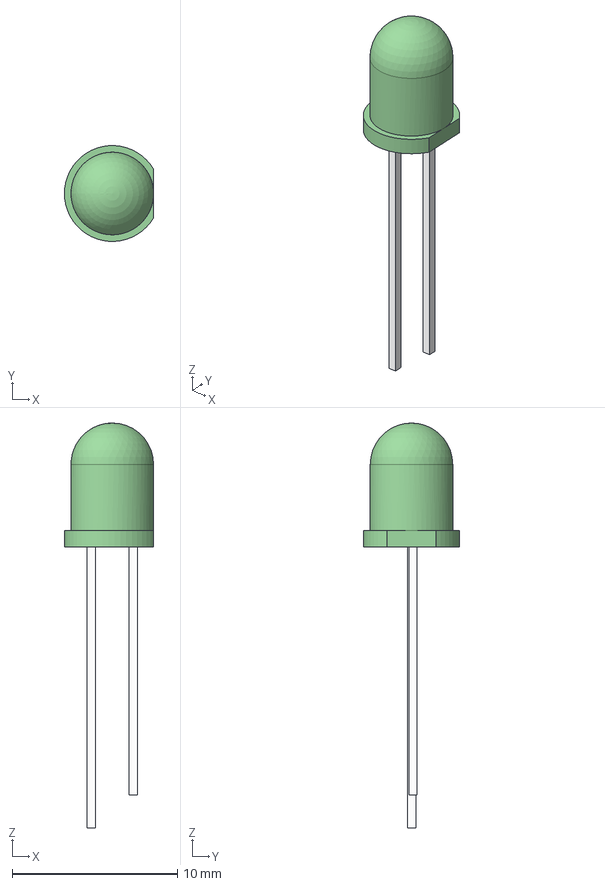
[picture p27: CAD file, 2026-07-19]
Hardware/Model/Parts/JesusMC_led 5mm v1.step
5.40 x 5.79 x 24.5 mm

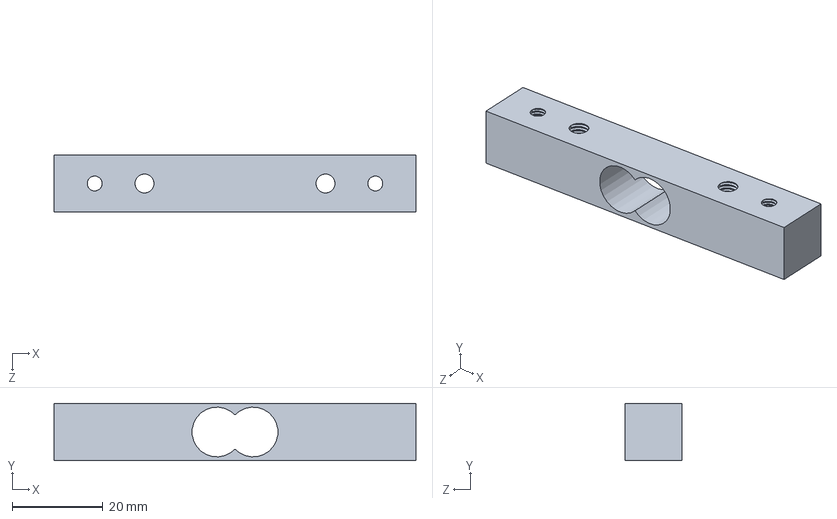
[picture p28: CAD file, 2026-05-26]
Hardware/Model/Parts/loadcell_10kg_tal220B.SLDPRT
80.0 x 12.7 x 12.7 mm

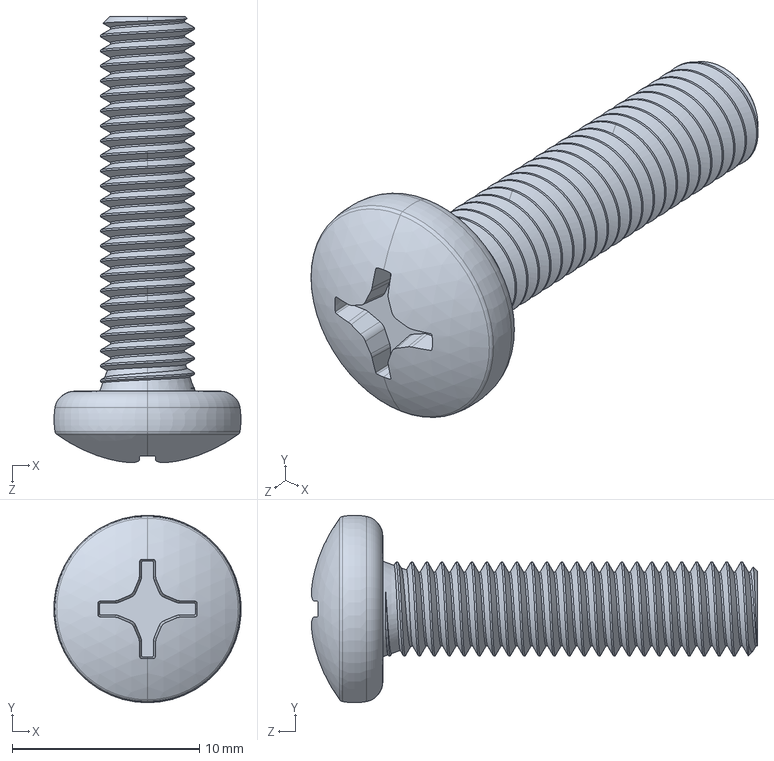
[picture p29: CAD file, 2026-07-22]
Hardware/Model/Parts/92000A328_Passivated 18-8 Stainless Steel Pan Head Phillips Screws.STEP
9.98 x 10.0 x 23.8 mm

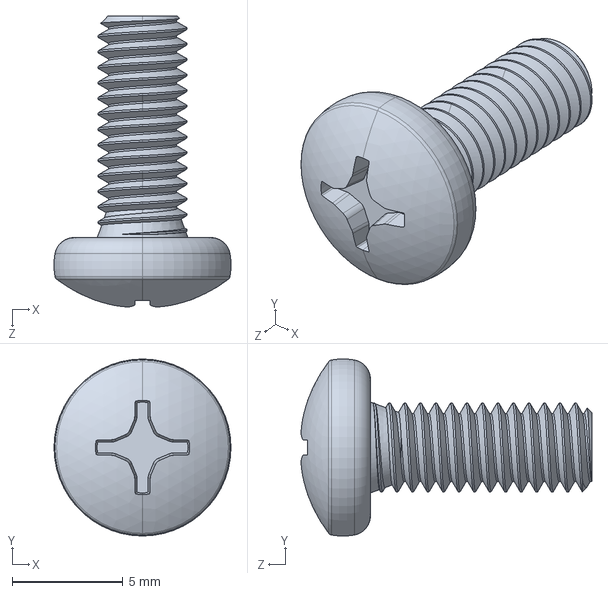
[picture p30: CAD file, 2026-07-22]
Hardware/Model/Parts/92000A220_Passivated 18-8 Stainless Steel Pan Head Phillips Screws.STEP
7.99 x 7.99 x 13.1 mm

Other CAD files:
Hardware/Model/Parts/0.9 inch I2C OLED 128×64 Display Module_jhalak/0.9 inch I2C OLED 128×64 Display Module_jhalak.ipt
Hardware/Model/Parts/0.96'' OLED Display/0.96'' OLED Display.ipt
Hardware/Model/Parts/92000A220_Passivated 18-8 Stainless Steel Pan Head Phillips Screws/92000A220_Passivated 18-8 Stainless Steel Pan Head Phillips Screws/92000A220_Passivated 18-8 Stainle.ipt
Hardware/Model/Parts/92000A328_Passivated 18-8 Stainless Steel Pan Head Phillips Screws/92000A328_Passivated 18-8 Stainless Steel Pan Head Phillips Screws/92000A328_Passivated 18-8 Stainle.ipt
Hardware/Model/Parts/GUZIK.ipt
Hardware/Model/Parts/JesusMC_led 5mm v1/JesusMC_led 5mm v1/JesusMC_led 5mm v1.ipt
Hardware/Model/Parts/LoadCell-20kg-80mm/LoadCell-20kg-80mm.ipt
Hardware/Model/Parts/LoadCell-NA151x75mmL/LoadCell-NA151x75mmL.ipt
Hardware/Model/Parts/Micro_Button_6x6.STL
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

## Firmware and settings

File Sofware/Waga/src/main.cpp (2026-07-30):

#include <Arduino.h>
#include <HX711.h>
#include <Wire.h>
#include <Adafruit_GFX.h>
#include <Adafruit_SSD1306.h>

#define i2cAddress 0x3c
#define SCREEN_WIDTH 128
#define SCREEN_HEIGHT 64
#define OLED_RESET -1
Adafruit_SSD1306 display(SCREEN_WIDTH, SCREEN_HEIGHT, &Wire, OLED_RESET);
HX711 scale;

// Configuration
const int doutPin = 2;
const int sckPin = 3;
const uint8_t tarePin = 5;
const uint8_t ledPin = 6;
static float scaleFactor = 232.39f;
float filteredWeight = 0;
bool initialized = false;

float calibrationCorrection(float grams)
{
  if (grams <= 500.0f)
    return grams;

  return grams + 0.003965f * (grams - 500.0f);
}

void displayWeight(float grams)
{
  display.clearDisplay();
  display.setTextColor(SSD1306_WHITE);
  display.setTextSize(2);
  display.setCursor(0, 0);
  display.print("Weight:");
  display.setCursor(0, 30);

  if (abs(grams) < 1.0)
    grams = 0.0;
  if (grams >= 1000.0)
  {
    display.print(grams / 1000.0, 3);
    display.print(" kg");
  }
  else
  {
    display.print(grams, 2);
    display.print(" g");
  }
  display.display();
}

void tareScale()
{
  display.clearDisplay();
  display.setCursor(0, 0);
  display.setTextSize(1);
  display.setTextColor(SSD1306_WHITE);
  display.print("Zeroing...");
  display.display();

  scale.tare(25);
  filteredWeight = 0;
  initialized = true;
  Serial.println("Tare completed.");
}

float getWeightResult()
{
  if (scale.is_ready())
  {
    float newReading = calibrationCorrection(scale.get_units(2));

    float difference = abs(newReading - filteredWeight);

    float dynamicAlpha = (difference > 1.0f) ? 0.85f : 0.1f;

    filteredWeight =
        dynamicAlpha * newReading +
        (1.0f - dynamicAlpha) * filteredWeight;

    return filteredWeight;
  }

  return filteredWeight;
}

void setup()
{
  Serial.begin(9600);
  pinMode(tarePin, INPUT_PULLUP);
  pinMode(ledPin, OUTPUT);
  digitalWrite(ledPin, HIGH);

  scale.begin(doutPin, sckPin);
  scale.set_scale(scaleFactor);

  if (!display.begin(SSD1306_SWITCHCAPVCC, i2cAddress))
  {
    Serial.println(F("OLED error"));
  }
  else
  {
    display.clearDisplay();
    display.display();
  }

  tareScale();
}

void loop()
{
  if (digitalRead(tarePin) == LOW)
  {
    tareScale();
    delay(200);
  }

  float currentWeight = getWeightResult();

  Serial.print("Weight: ");
  Serial.print(currentWeight);
  Serial.println(" g");

  displayWeight(currentWeight);

  delay(1);
}

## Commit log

2026-07-19 finished model files
    [0.9 inch I2C OLED 128×64 Display Module_jhalak.step, JesusMC_led 5mm v1.ipt, JesusMC_led 5mm v1.step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]
2026-07-21 Added needed files
    [0.9 inch I2C OLED 128×64 Display Module_jhalak.ipt, 0.9 inch I2C OLED 128×64 Display Module_jhalak.step, 0.96'' OLED Display.ipt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]
2026-07-22 Migration of model parts and fixing some dependencies
    [0.9 inch I2C OLED 128×64 Display Module_jhalak.ipt, 0.96'' OLED Display.ipt, 0.96'' OLED Display.step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]
2026-07-23 A subsection on basic calibration and validation software has been added
2026-07-26 First iteration od advanced calibration software
2026-07-26 Added dynamic filter for faster response
2026-07-30 New scaling correction function added
    [main.cpp]
